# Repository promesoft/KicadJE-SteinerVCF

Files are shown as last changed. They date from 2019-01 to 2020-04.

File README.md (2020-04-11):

# Johansen Engineering Steiner VCF RevB

# Status - VCF working
## Initial 
| Stage  | Detail | Status |
| --- | --- | --- |
| create material  | sch/pcb | OK  |
| | gerber | OK |
| production  | | OK |
|  | produced | OK |
|  | delivered | Delivered |
## Preliminary validation
| Test  | Detail | Status |
| --- | --- | --- |
| Initial Inspection | VCO | OK - bottom looks empty w/o gnd fill |
| Initial Inspection | VCF | OK - bottom looks empty w/o gnd fill |
| | | Very difficult to mount as footprints are getting over soldering points in many places|
| | | BP in the bottom |
| | | HP in the middle |
| | | LP on top |
| Initial Inspection | VCF SMD | OK - bottom looks empty w/o gnd fill |
| Initial Technical Test | VCO | SINE has PCB error - and Sine pot has +12V to chassis |
| Initial Technical Test | VCF | One pot gets -12v on chassis |
| Initial Technical Test | VCF SMD |  |
| Initial Product Test | VCO | Nice -  |
| Initial Product Test | VCF |  |
| | | CV1 and CV2 works fine |
| | | Q is doing something |
| | | Uncertain if the freq pot is right |
| Initial Product Test | VCF SMD|  |
## Secondary validation
| Test  | Detail | Status |
| --- | --- |--- |
| Product Test |  | |
| Product Test |  |  |
| Quality | | |
| Quality | | |
| Long Term Product Test |  |  |
| Power Draw | VCO | +12 4mA -12
| Power Draw | VCF | +12 8mA -12
| Power Draw | VCF SMD | +12 ?mA -12

## Errata
### Errata - VCO
* Due to footprint one of the pots gets -12v on chassis

* Sine signal is shorted to GND

* Glide pot is reversed

### Errata - VCF
* Due to footprint one of the pots gets -12v on chassis

* R127 - DNP (Do not populate)

* R119 swap with 220nF-1uF to ac couple input stage

* R126 swap with 1uF to ac couple input stage

### Errata - VCF SMD

## Issues and Notes
### VCF
Very difficult to mount as footprints are getting over soldering points in many places
### VCO
 * Remove output pots
 * Collect jacks in the bottom
 * Fix errors (glide,  POT, PCB errors, footprint tightened)
 * Consider removing sine shaper
# Pictures
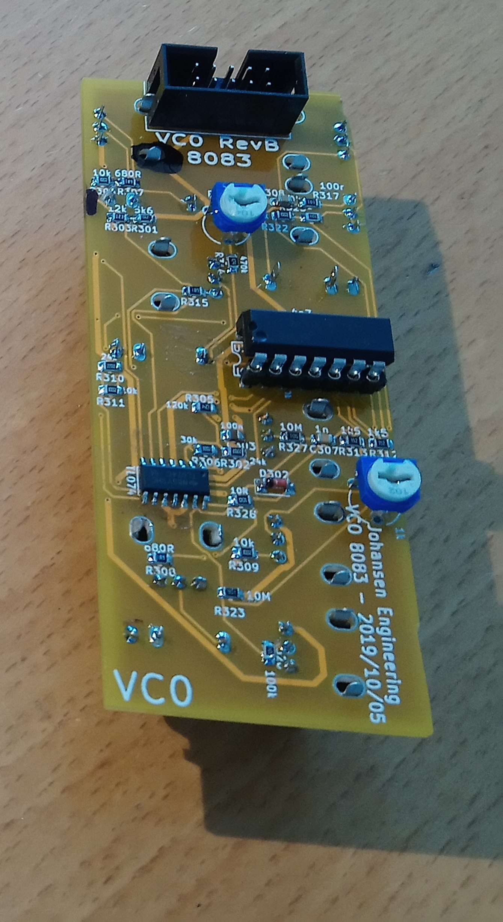
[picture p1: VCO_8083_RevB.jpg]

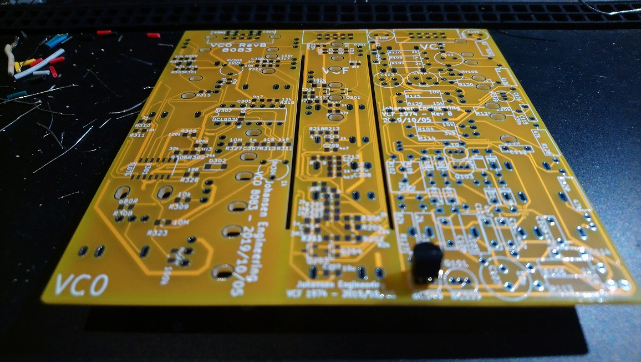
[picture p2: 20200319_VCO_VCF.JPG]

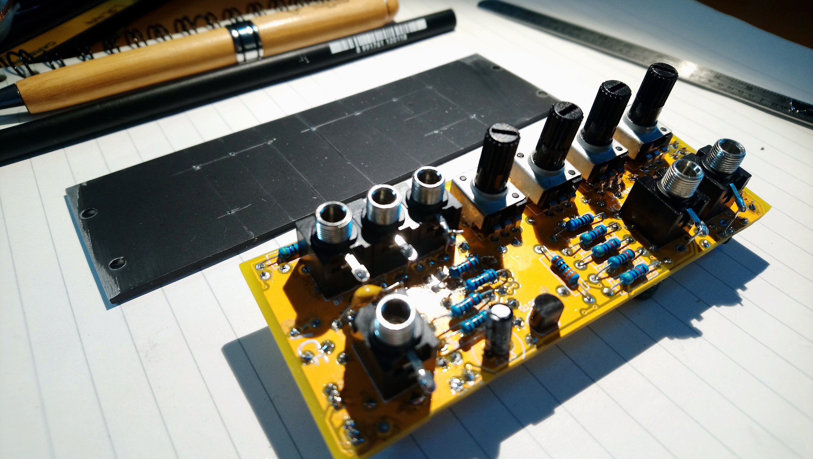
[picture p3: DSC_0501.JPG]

# Schematic
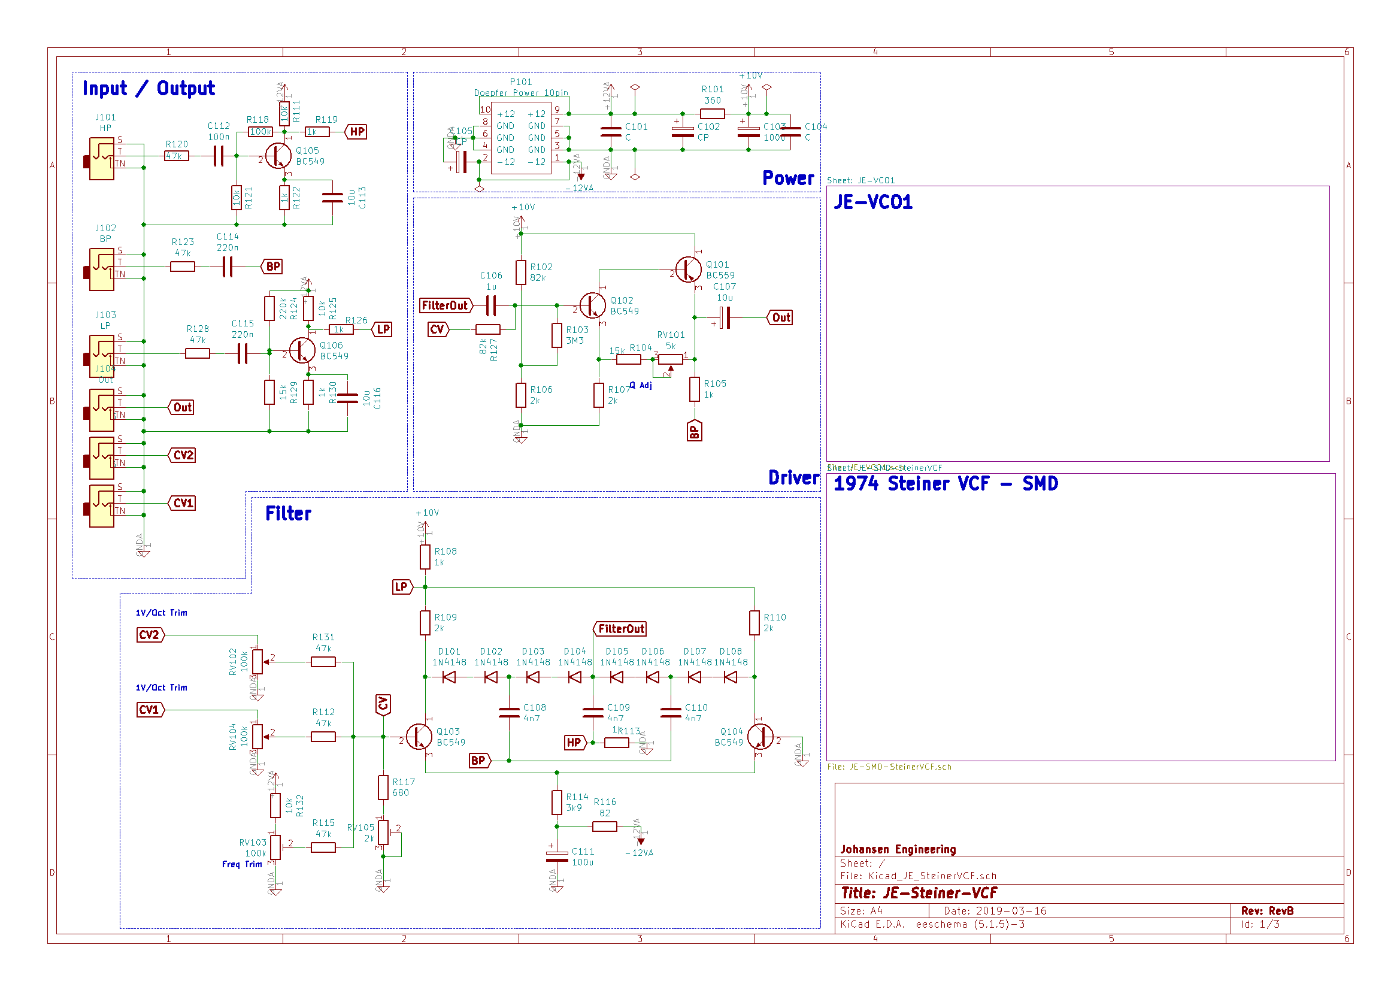
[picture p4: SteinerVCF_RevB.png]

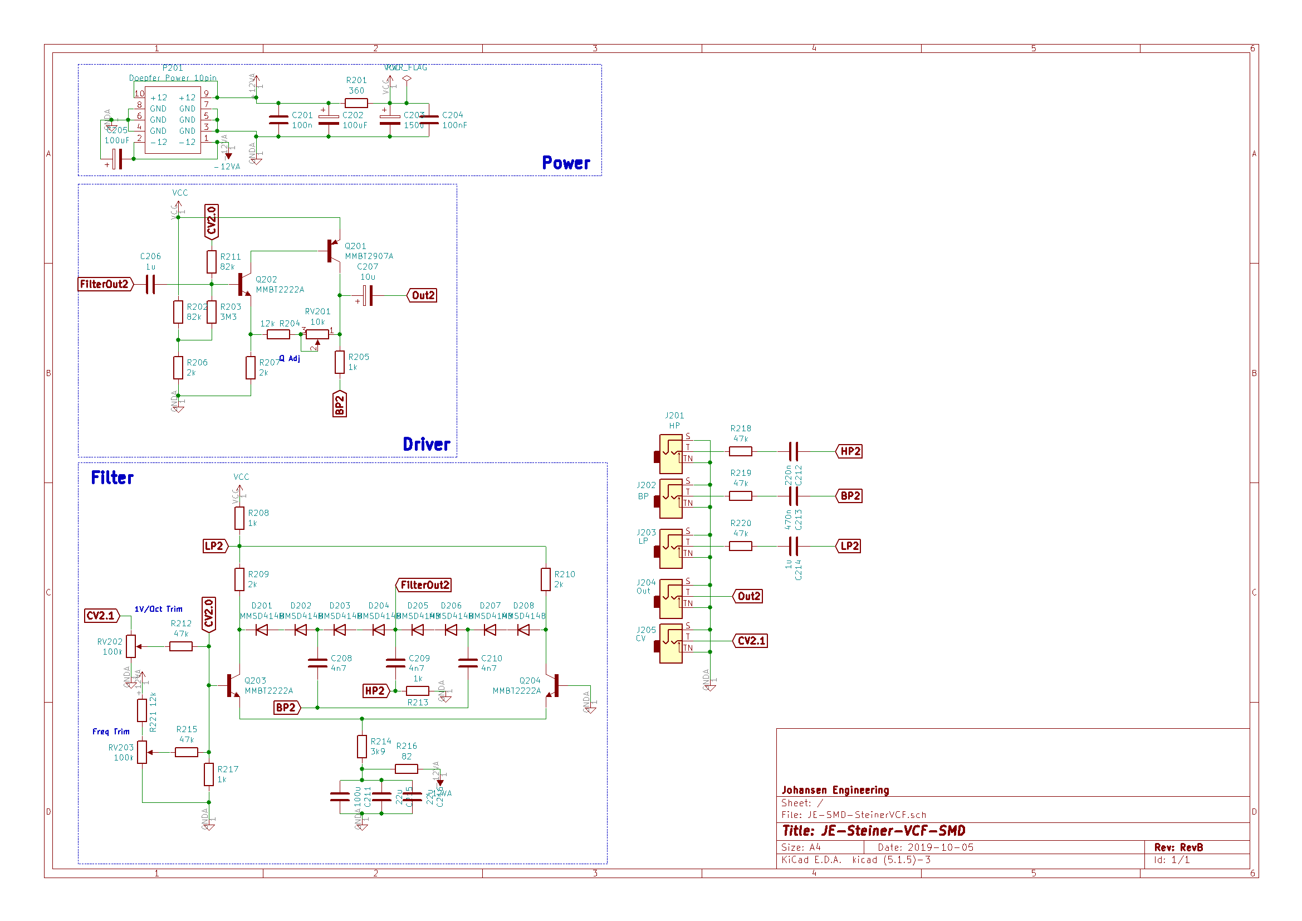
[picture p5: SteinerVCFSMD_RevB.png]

# Layout

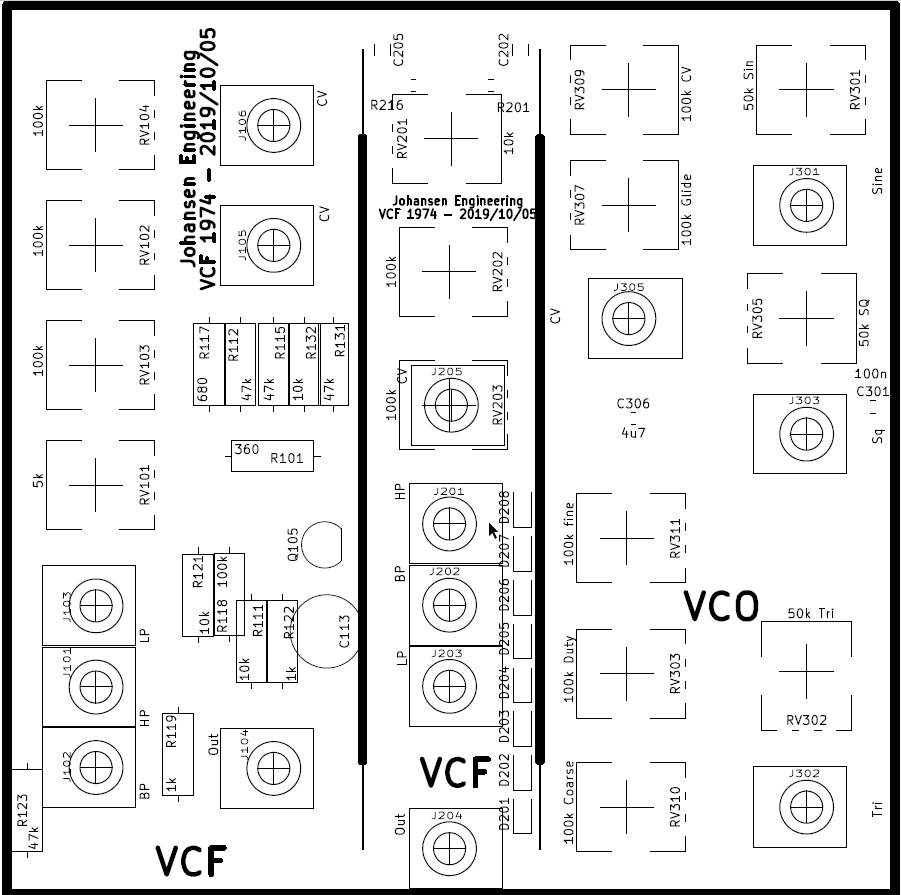
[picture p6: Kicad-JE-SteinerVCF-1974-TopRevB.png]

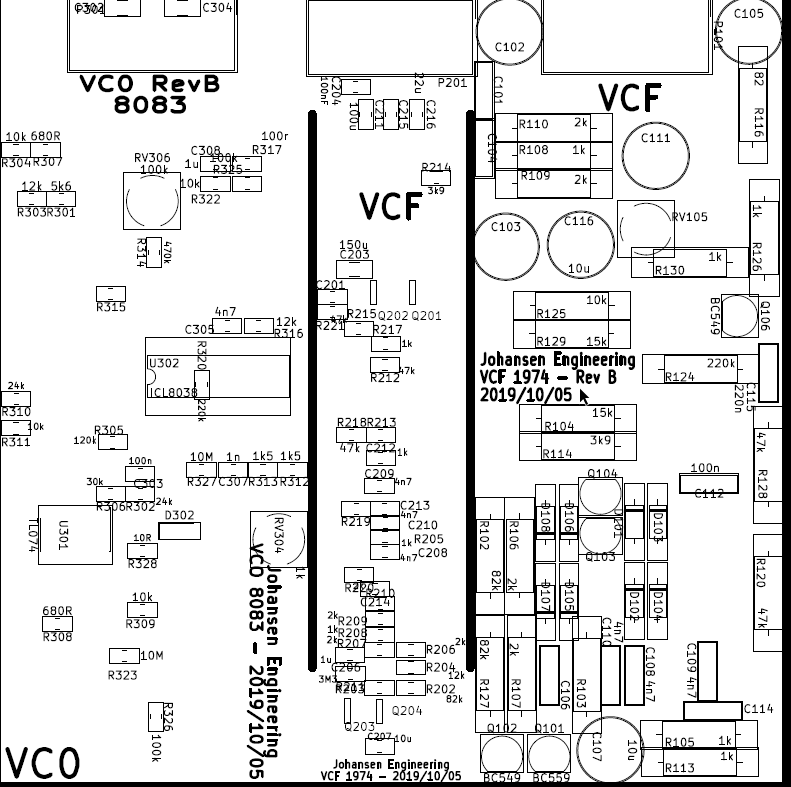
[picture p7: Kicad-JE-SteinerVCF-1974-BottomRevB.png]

# Inspiration

-----------------------

# Johansen Engineering Steiner VCF

# Purpose
Test some of the original designs for inspiration and reference.

# Status - Preliminary tests
## Initial 
| Stage  | Detail | Status |
| --- | --- | --- |
| create material  | sch/pcb | produced Rev A  |
| | gerber | produced and uploaded RevA |
| production  | ordered  | OK |
|  | produced | OK |
|  | delivered | OK |
## Preliminary validation
| Test  | Detail | Status |
| --- | --- | --- |
| Initial Inspection | THT VCF - Visual - Component Mounting | NOT OK |
| Initial Inspection | SMD VCF - Visual - Component Mounting | NOT OK |
| Initial Inspection | VCO  - Visual - Component Mounting | OK |
| Initial Technical Test | THT VCF - Base operation | NOT OK |
| | Knobs | Freq working for LP - Q for HP/BP - CV trim - not ok|
| Initial Technical Test | SMD VCF | NOT TESTED |
| Initial Technical Test | VCO  - Sine - Triangle - Square | OK |
| | Trimmers | OK |
| | Knobs | OK |
| Initial Product Test | VCO CV from LFO | OK |
| | VCO Vactrol CV from LFO | no real effect with CV coupling |

## Secondary validation
| Test  | Detail | Status |
| --- | --- |--- |
| Product Test | VCF | |
| Product Test | VCO | Works nicely - frequency is a bit high |
| Quality | VCF | |
| Quality | VCO | |
| Long Term Product Test | VCO | OpAmp gets hot - esp if no output is conn to the square |
| Power Draw | VCO | 50-120mA depending on output...

## Errata
### Errata - THT VCF
 * C111 reverse polarity
 * R102 should go from +10v to connection between R103 and R106 - and +10v sould not go to Q102 base - Critical
### Errata - SMD VCF
 * R should go from +10v to connection between R and R - and +10v sould not go to Q base - Critical
### Errata - VCO
 * 470K values not correct for all resistors
 * 0R values not correct - fixed in RevB
 * Outputs should not be shorted to GND when not connected
 
## Issues and Notes
### VCF THT/SMD
 * The filter needs adjustments and the feedback is not stable. a 56k from CV to base of Q102 helps a bit.
 * Input circuit for CV needs rework
 * Input series resistor and capacitor could be a good addon for the filter inputs
 * Frequency adjust seems to work for LP only
 * Q adjust is minor and seems to work on HP and a bit on BP

### VCO
 * Tweak values for better frequency range
 * Op Amp can get hot
 * Draws more power if nothing is inserted into the Square output?

# Physical Construction
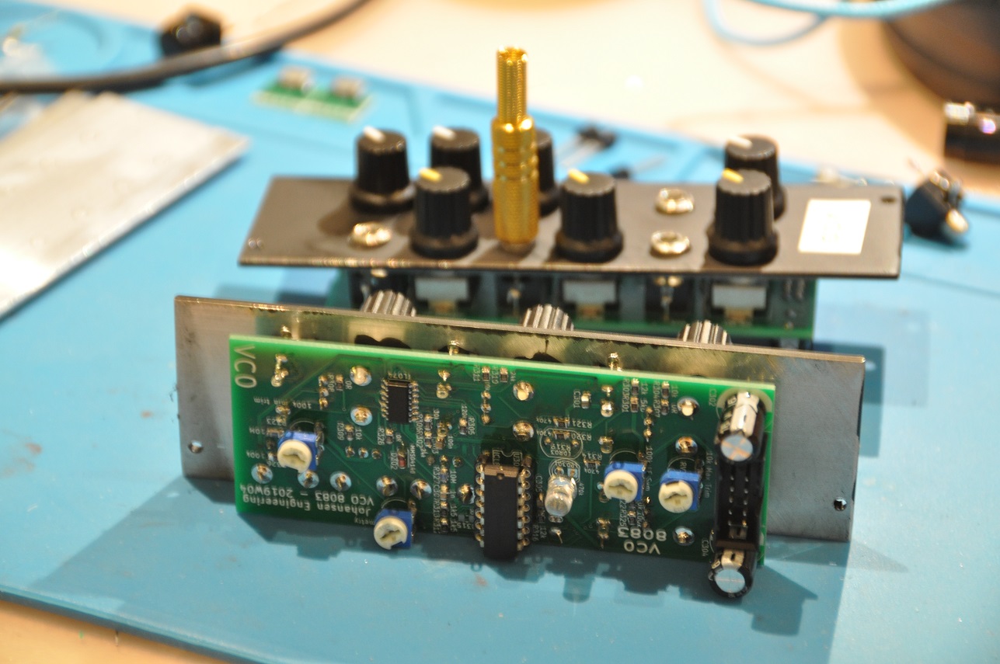
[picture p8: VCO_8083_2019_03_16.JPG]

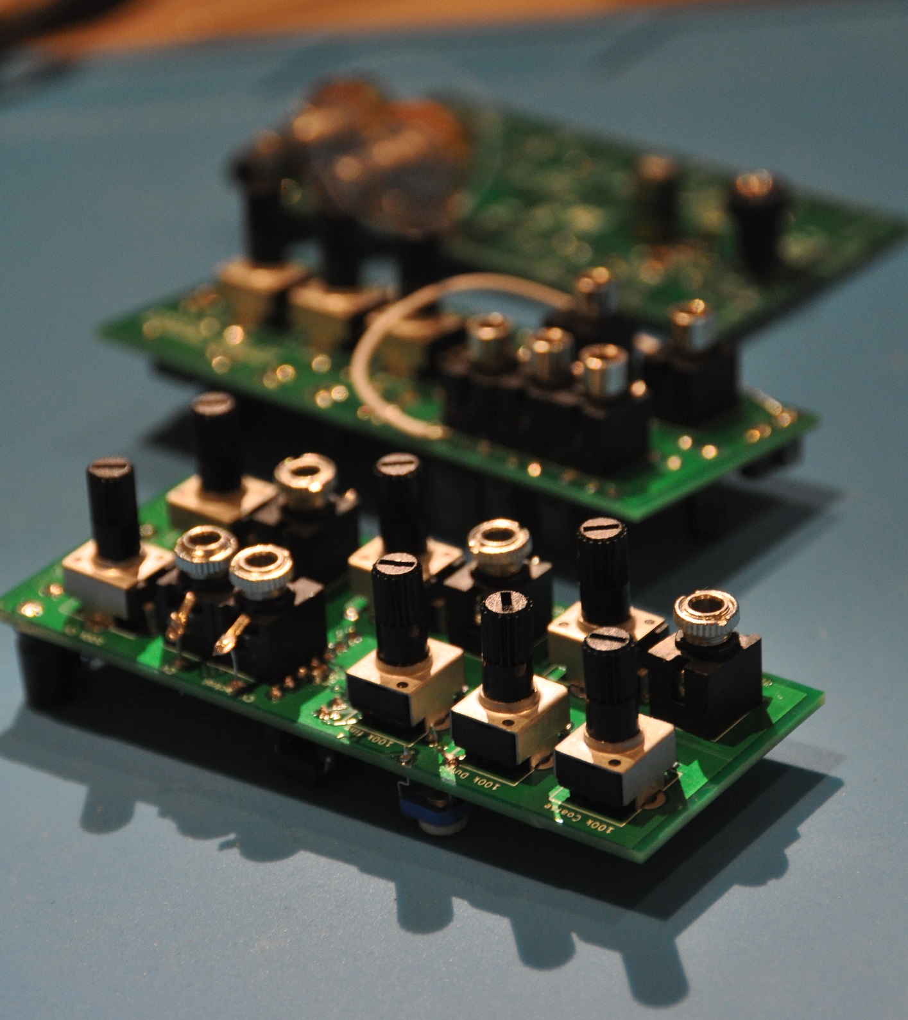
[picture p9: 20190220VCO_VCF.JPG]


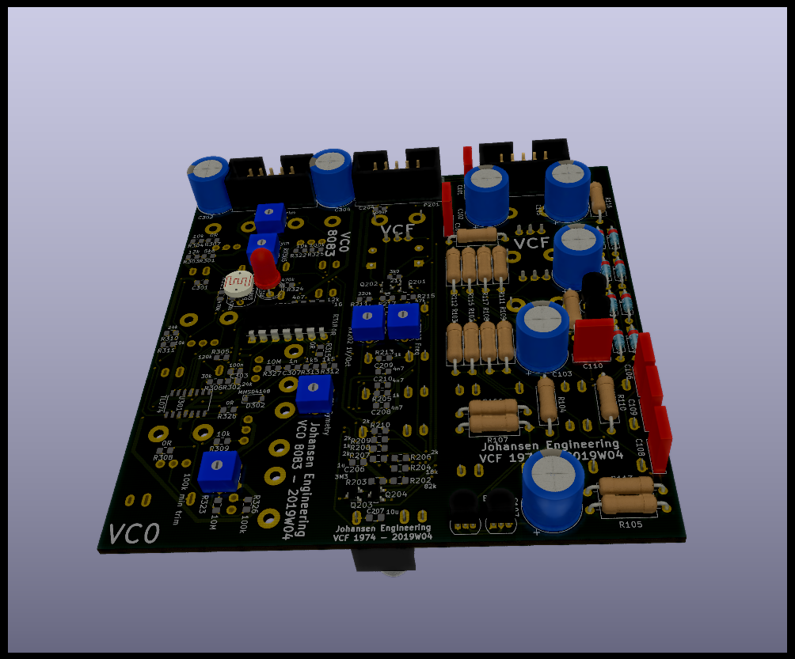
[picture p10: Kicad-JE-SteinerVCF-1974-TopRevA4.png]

# Features

## SMD VCF Schematic
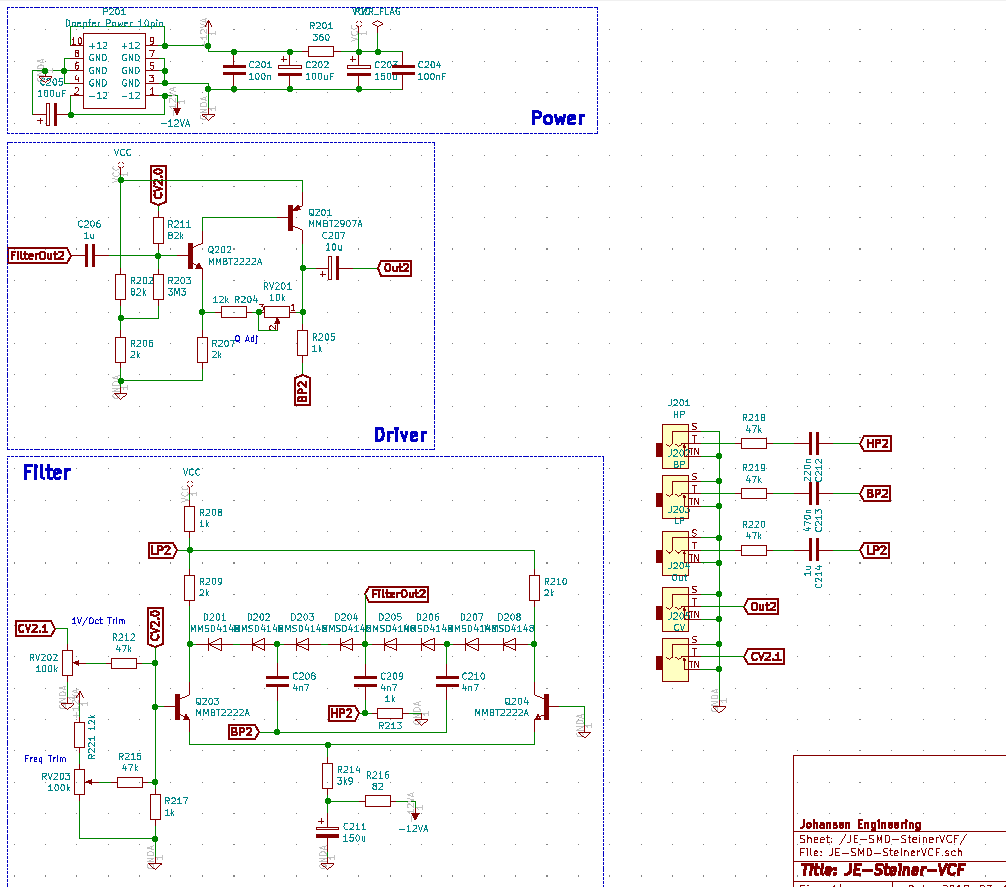
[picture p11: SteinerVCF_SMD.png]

## VCO Schematic
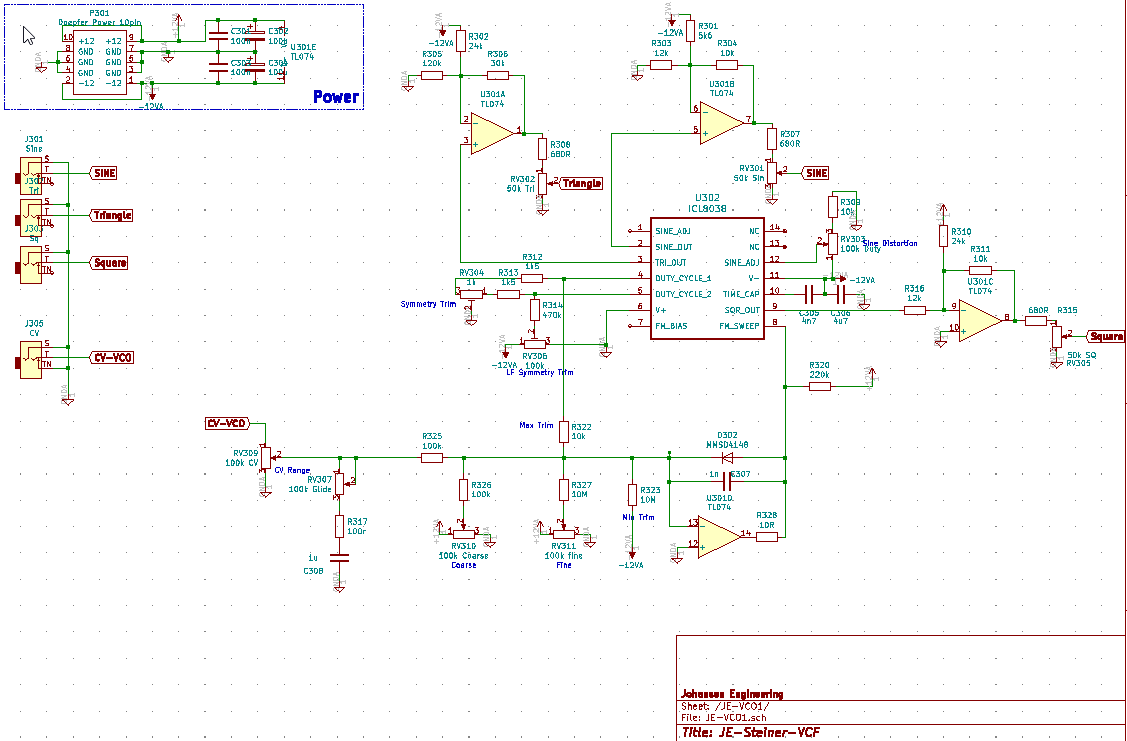
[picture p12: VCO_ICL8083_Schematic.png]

# Inspirational sources:
## Steiner VCF 1974 THT
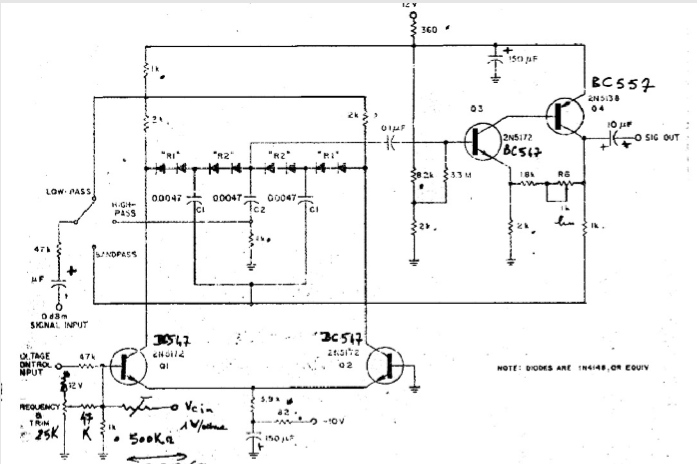
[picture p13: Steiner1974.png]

## Steiner VCF 1974 SMD
Same schematic - different components - half the size

## VCO ICL 8083
Based on a Thomas Henry schematic
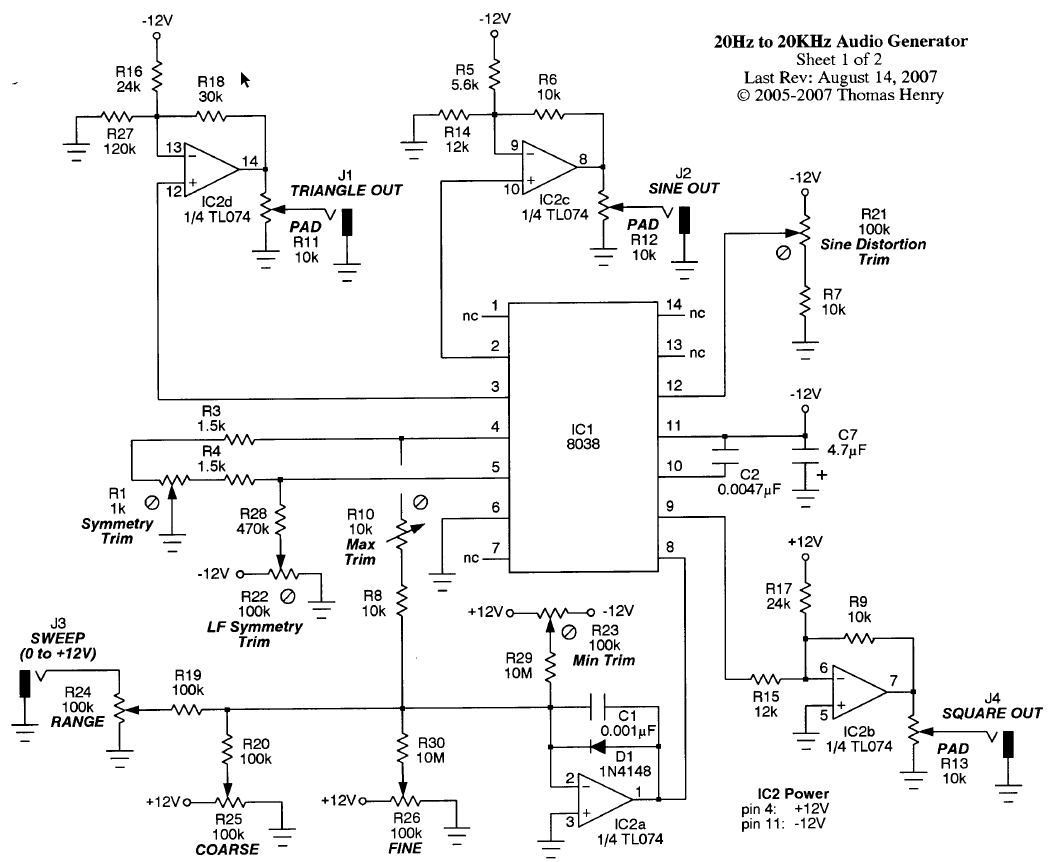
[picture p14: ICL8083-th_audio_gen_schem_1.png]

# Details

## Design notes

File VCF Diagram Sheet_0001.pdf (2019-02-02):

## ilns

## IHa TI A*

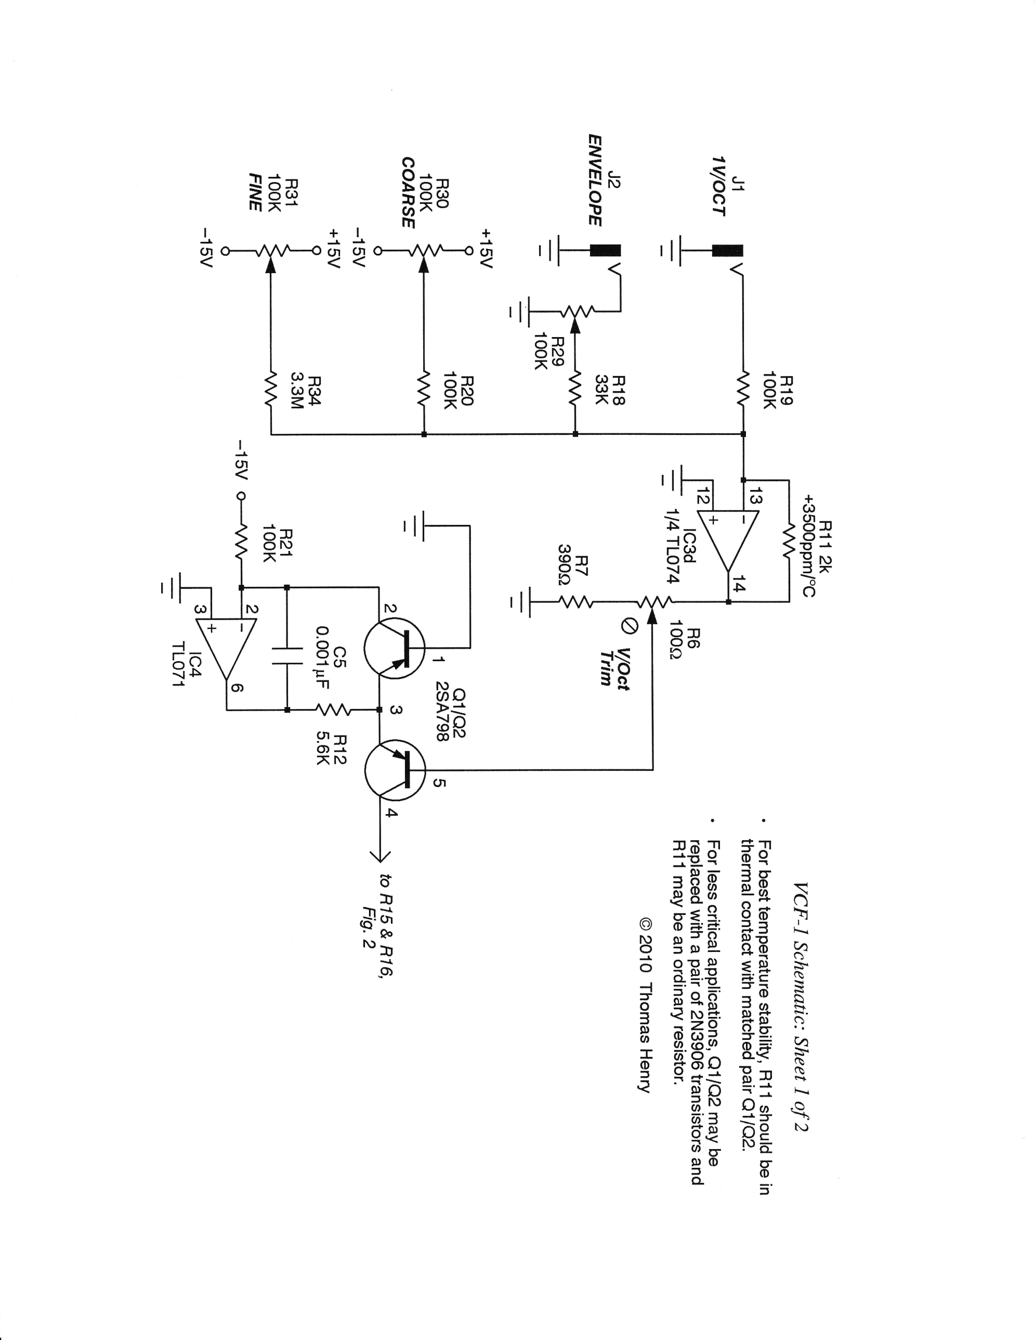
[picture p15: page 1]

S=o
a

rn

### =ffi- F f\)

o
!
rn

o
Q-r.-
n
+
..^(lt

+l
JJ(Jr (Fl

I
J,
(Jt

dru
5<o
ETxo

I
J
(lt
rl
+
(r)8r o-r. E-r E r\) 3x

o

o

J

s_
-rOrG) bo- N
s

(^)
H{

ofI
Eo.,

s

SEsg

{
5R | Bo>{

HC

# is{ tq

## Eilq *g E

## ,a ]c8. Ub' t

(J, o='=. +3 i.-.

# E silE HE K d:.EfiiPY

### # il-ail' lH $

3

# ft$HiilFF g ggg ga s

## d ru gE 'e.. 6'3 qE Ri N)

@ o l-o' 3.' q

s
b
.$* *r

-9)

p
8o
-r. (J1
.TI

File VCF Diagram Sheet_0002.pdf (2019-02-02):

# =b(n. pEh

b

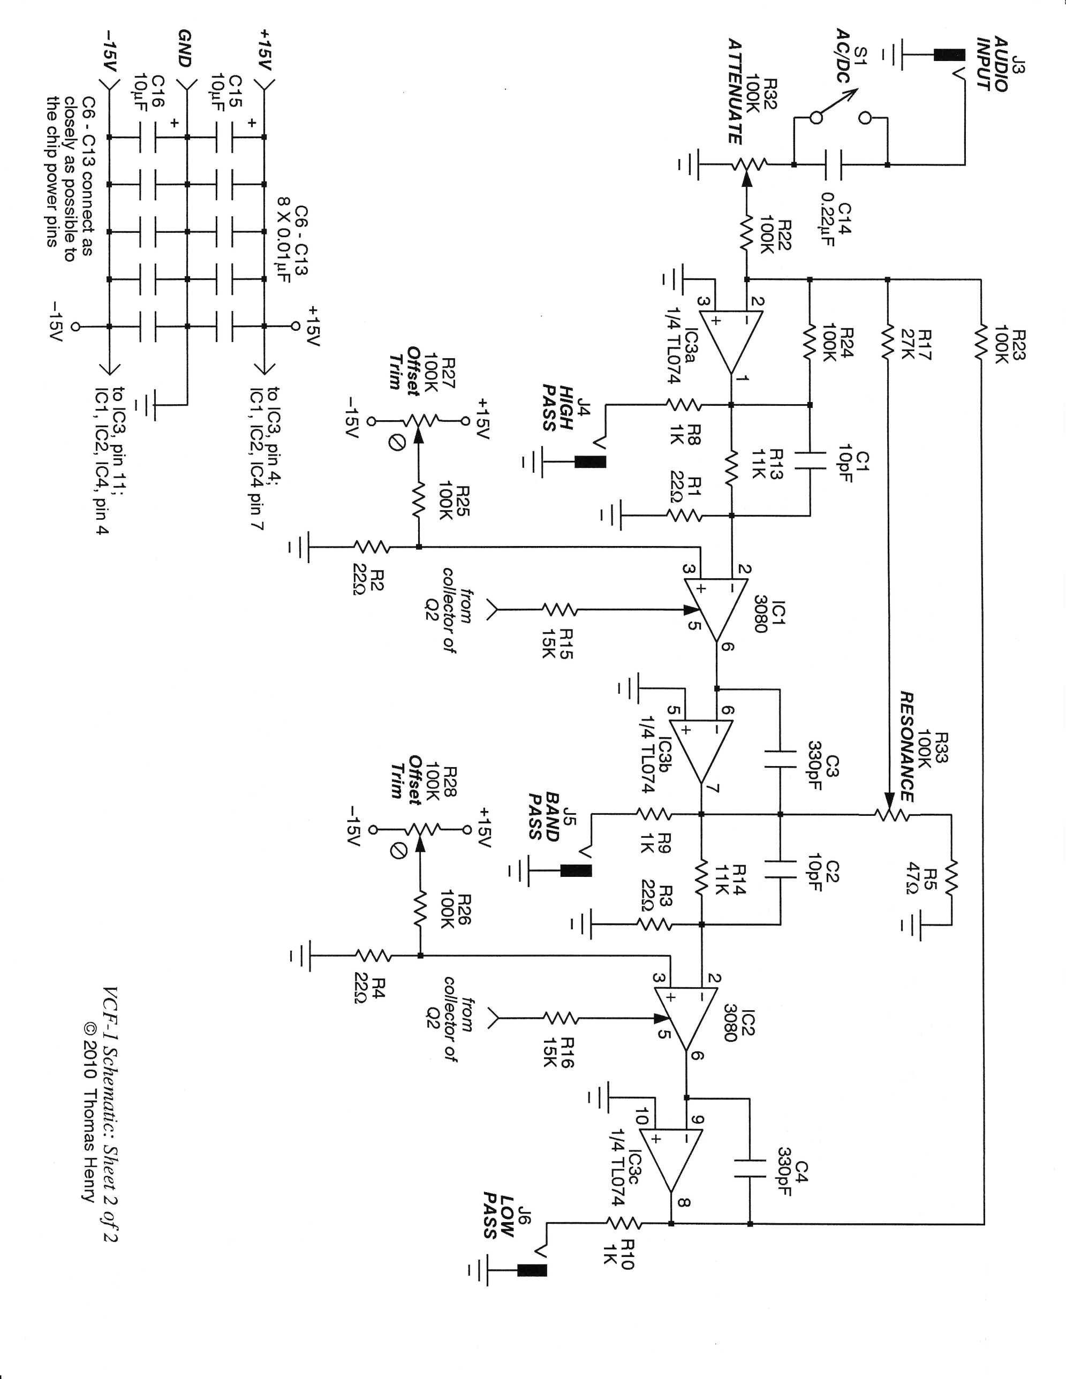
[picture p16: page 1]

\- qr io

# Qoq) "r o

o

# luO

# nru

Pi

@
x$

# 9l qo

\c,r

# dru 5 <r)

.J,

s_

# -rOr- G) bs) \ls

rl

## bahl

# Hnru t

+oo
l-43
E;q

# : o.6 9.oo

a 6-;'
6o
rl

# -Ln Xco

J, -t
-Jt /\@

+

### ..4(lt I

(Jt

# $$dru s Ex!

# e Er- I J

(Jt

# ooo

6J' Np.

R+
p. J\

# ooo

oJ')
J\)E.

# O..^ S.-r

## p.fs

N- i$r | I
P tu | oFd' *qso\

rl

rl

Nn fA' J,

### rrJ

J, TI

## crr

a

# xcrt

6
G) u

## .Js{ro{

# $fins

s
TE

# + bbc- E EE' I

J,
(Ft
rl
Na

d47\o)

N'-'
O

# Ed5 q$$

";

d\
6 r'
v l-...

# Hr o$"

# -rSs's qR. JA

$ t'
@C4
+\rI r\)
d-R
aN)\

t\)

6
G) o

J,s{

r-o{
!r

# 5 birc-

E='

# ..r JI

--L/\o

+{

Ot

# oeU I{

(Jt

# nru

J,

# lo oO

r\)
T

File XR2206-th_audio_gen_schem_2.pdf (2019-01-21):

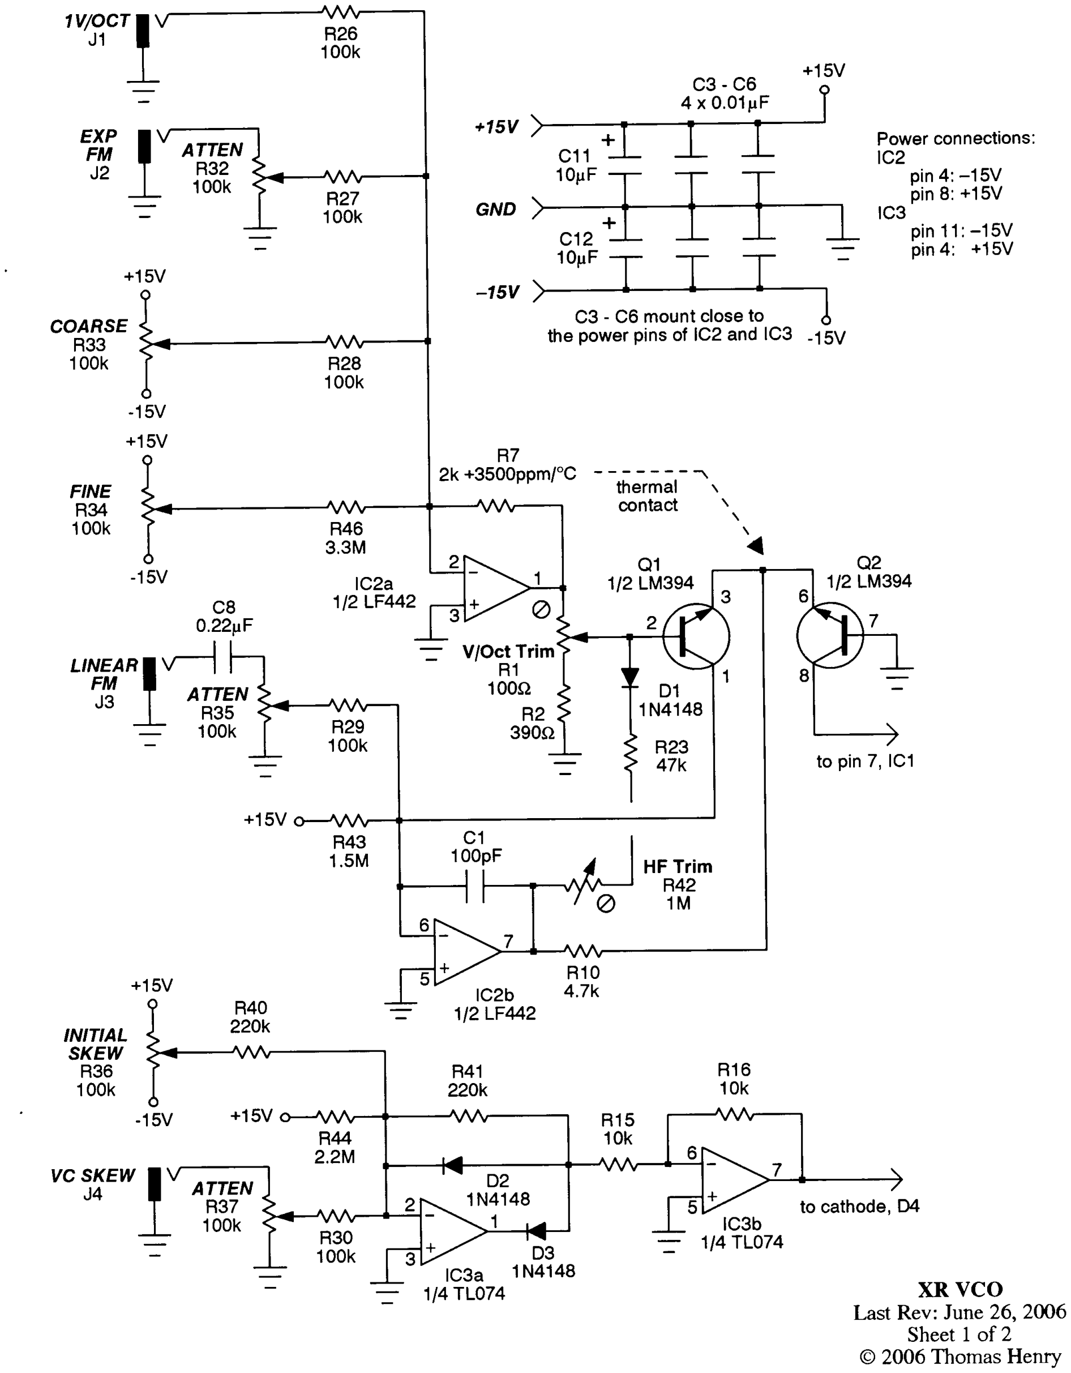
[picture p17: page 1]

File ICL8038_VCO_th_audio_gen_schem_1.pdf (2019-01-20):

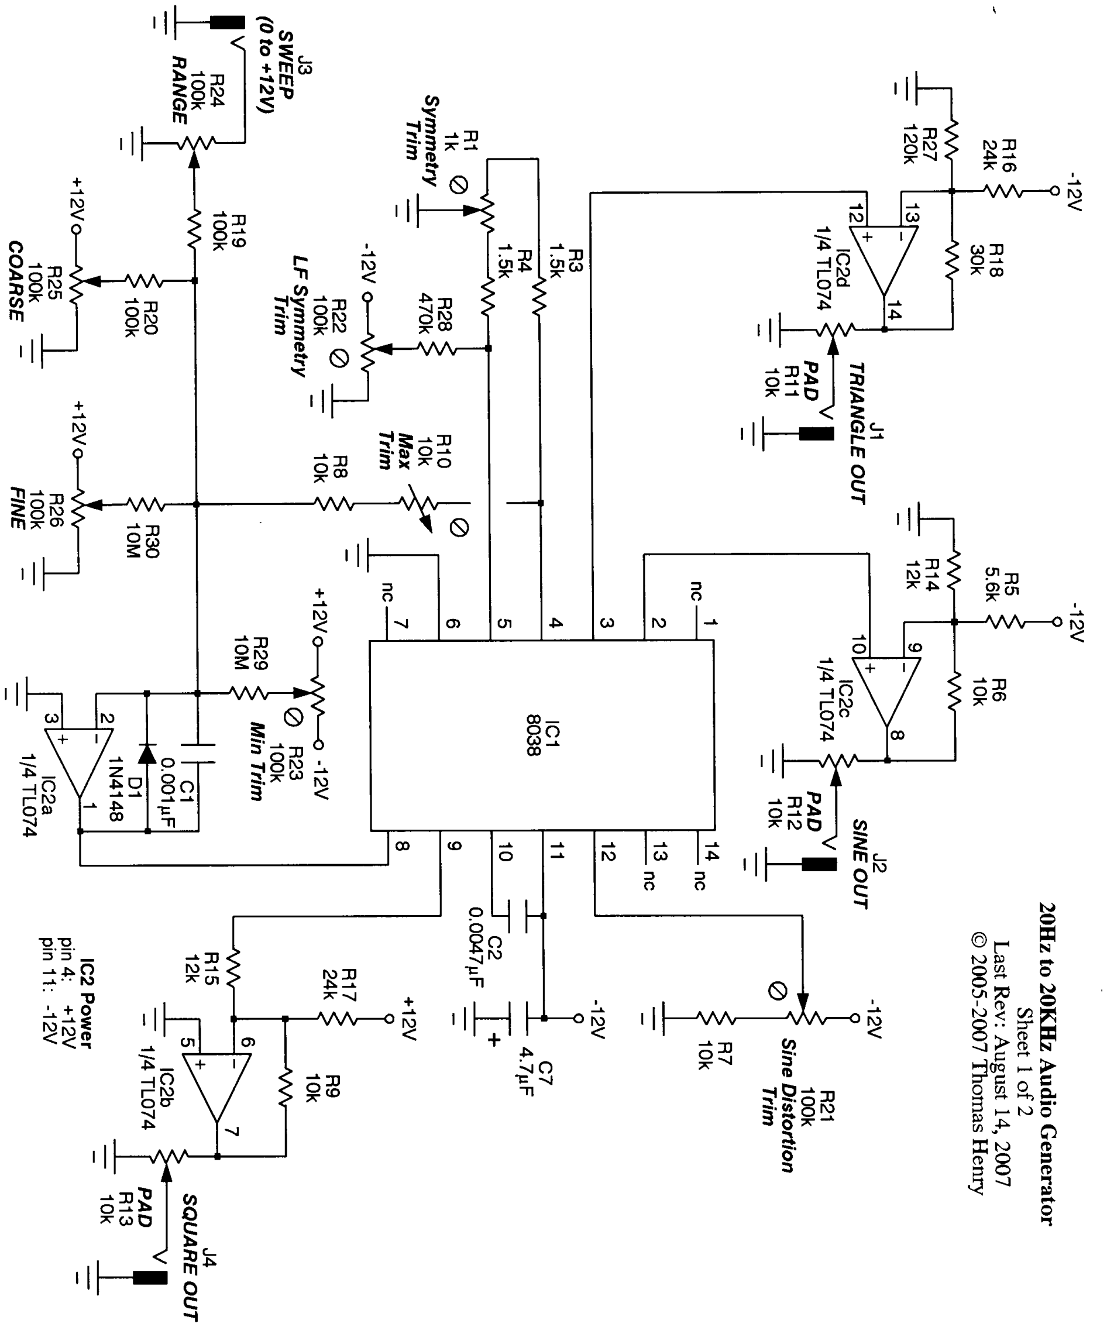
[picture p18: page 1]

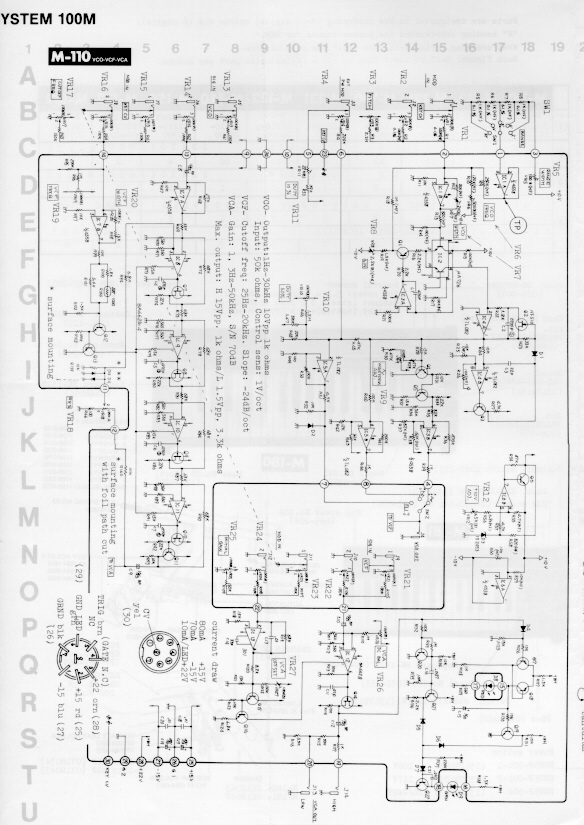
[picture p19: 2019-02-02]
VCO_schematic_s100m02b.jpg

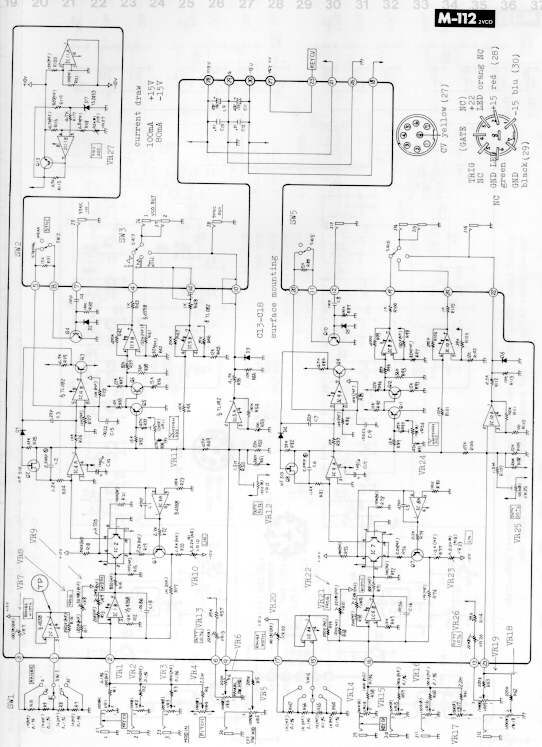
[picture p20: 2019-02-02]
VCO_schematic_s100m03b.jpg

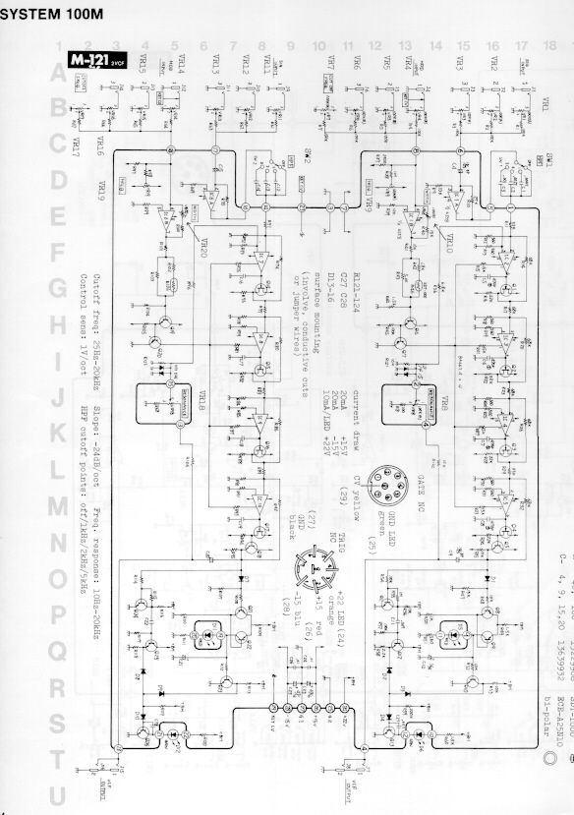
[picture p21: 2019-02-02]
VCF_schematic_s100m04b.jpg

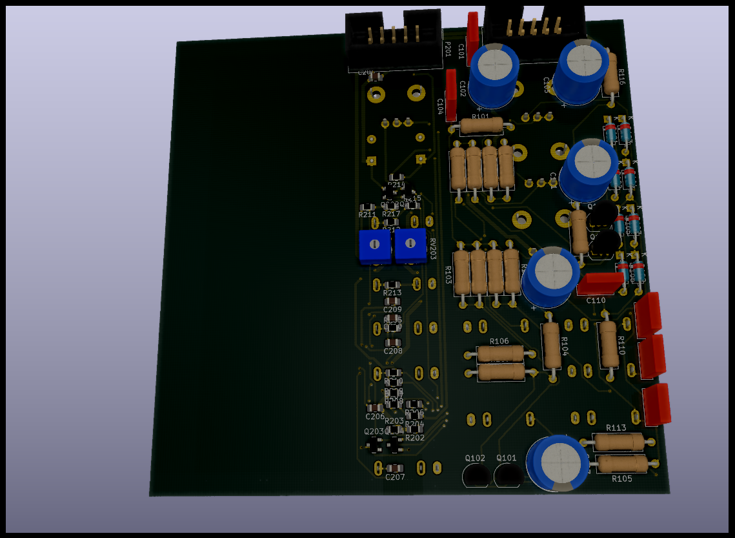
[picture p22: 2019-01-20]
Kicad-JE-SteinerVCF-1974-TopRevA1.png

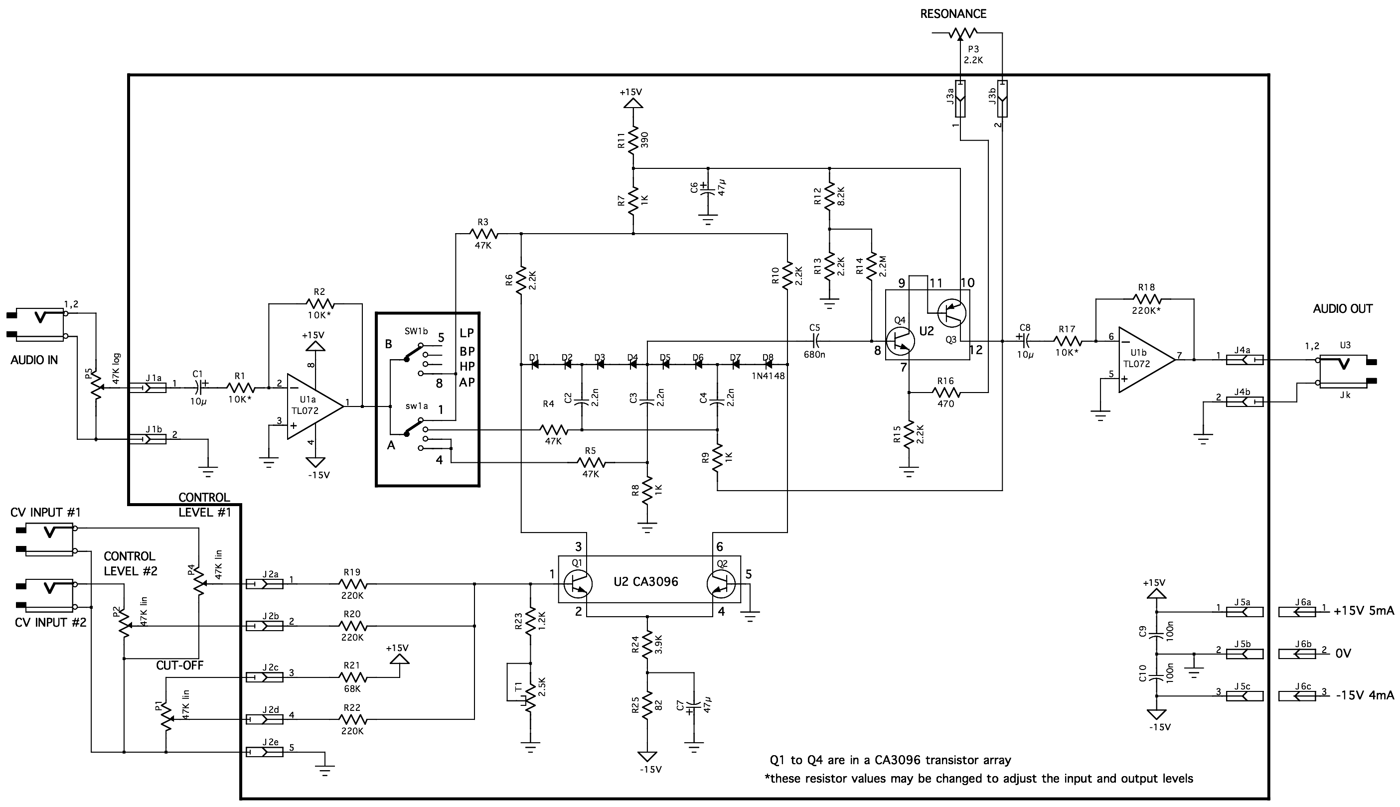
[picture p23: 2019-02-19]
VCF-CA3096-sch-yusynth.net.gif

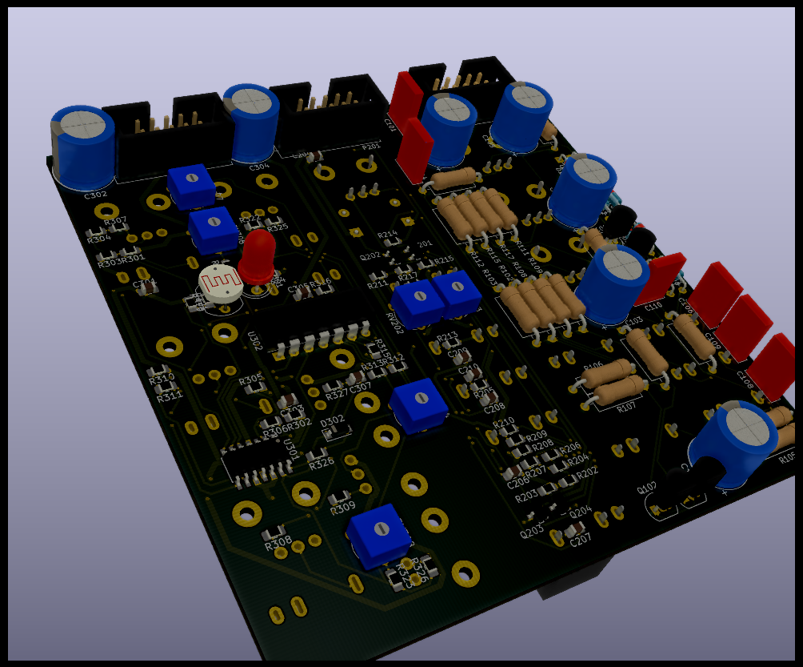
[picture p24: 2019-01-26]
Kicad-JE-SteinerVCF-1974-TopRevA3.png

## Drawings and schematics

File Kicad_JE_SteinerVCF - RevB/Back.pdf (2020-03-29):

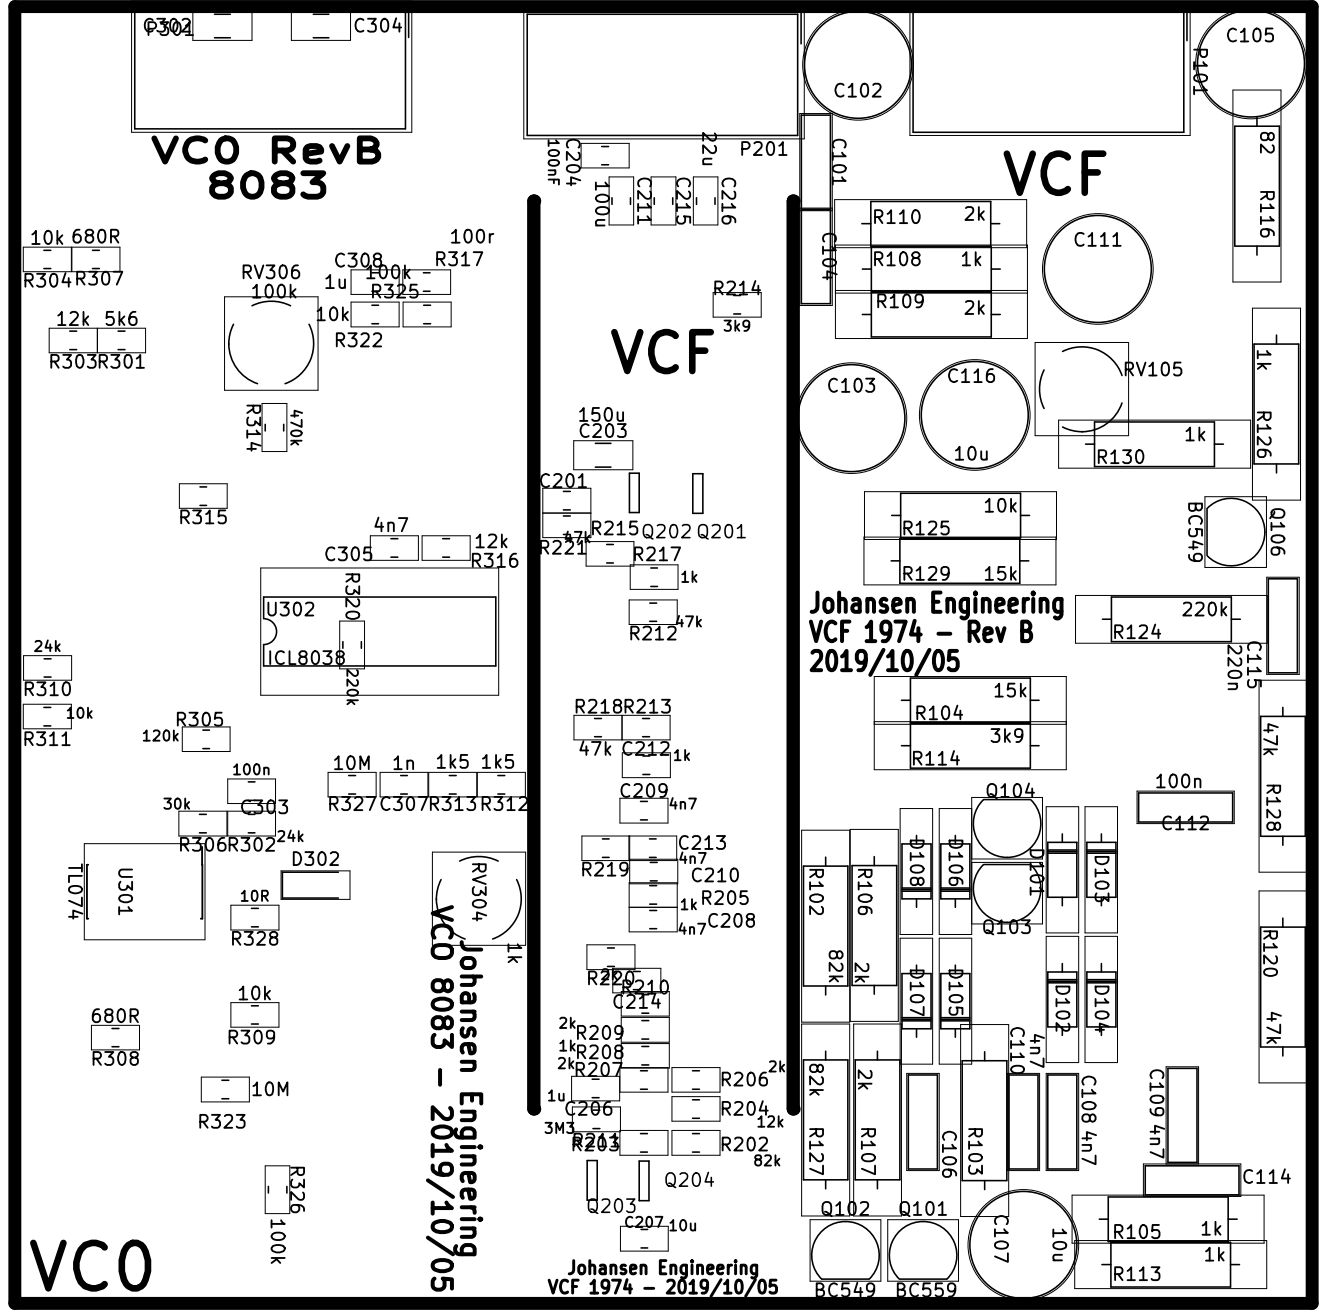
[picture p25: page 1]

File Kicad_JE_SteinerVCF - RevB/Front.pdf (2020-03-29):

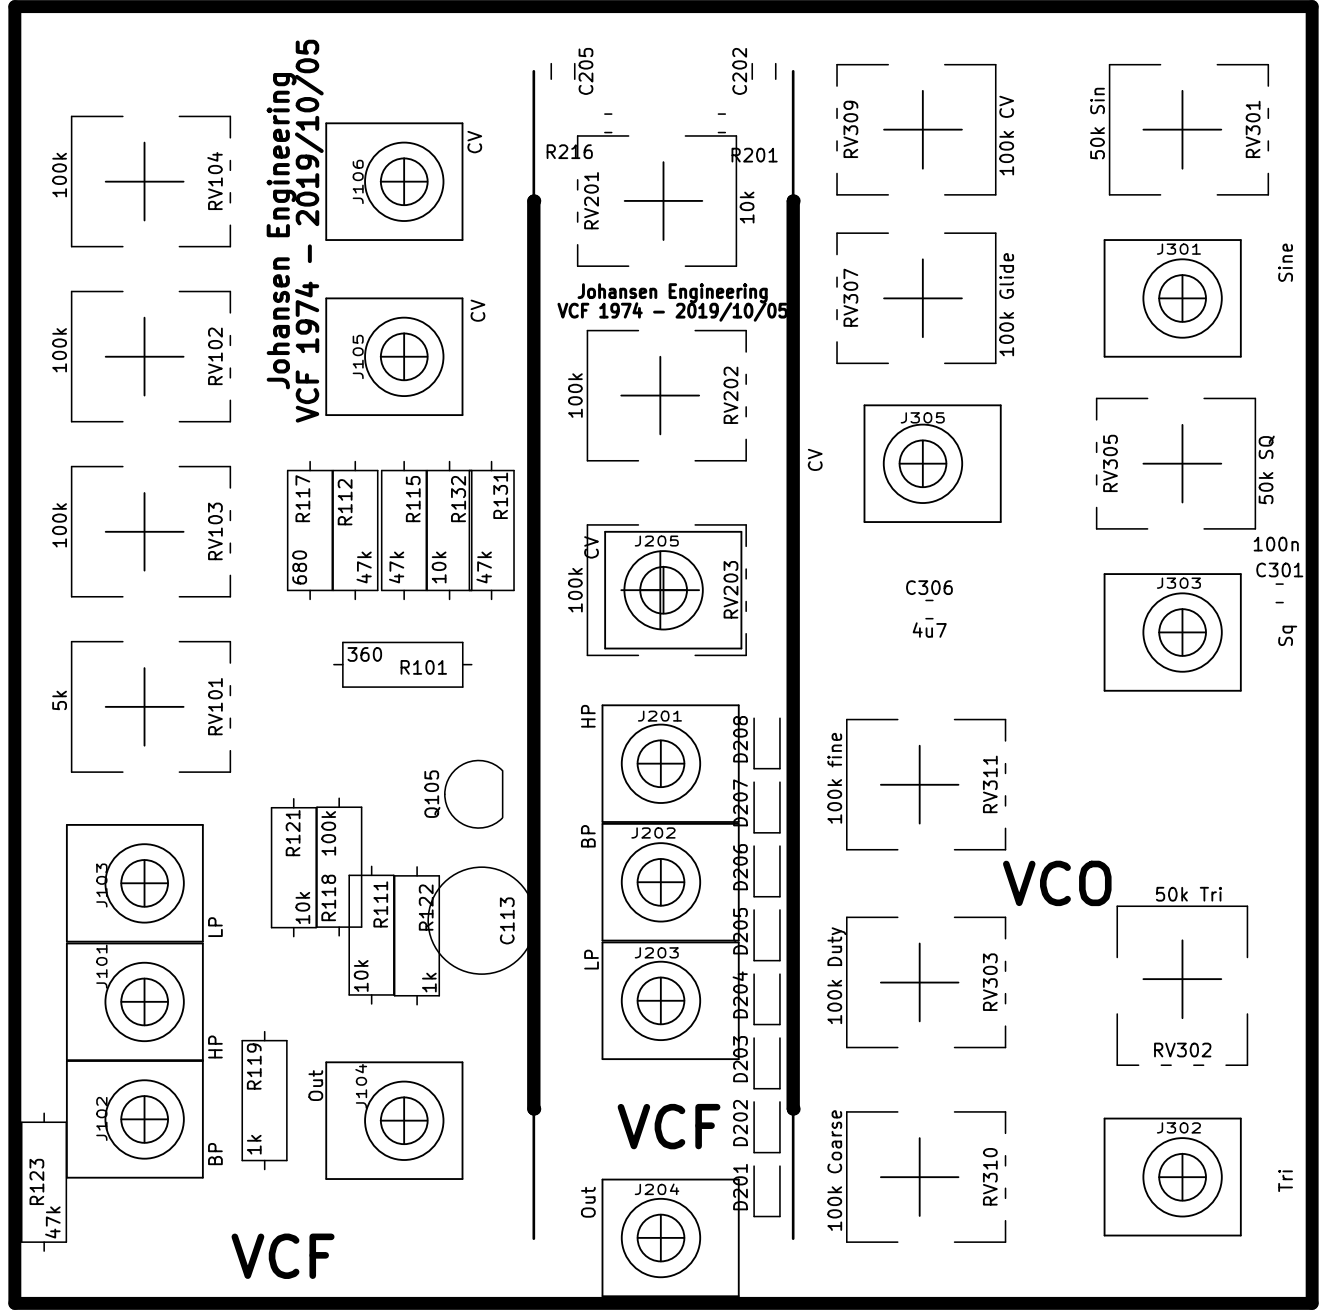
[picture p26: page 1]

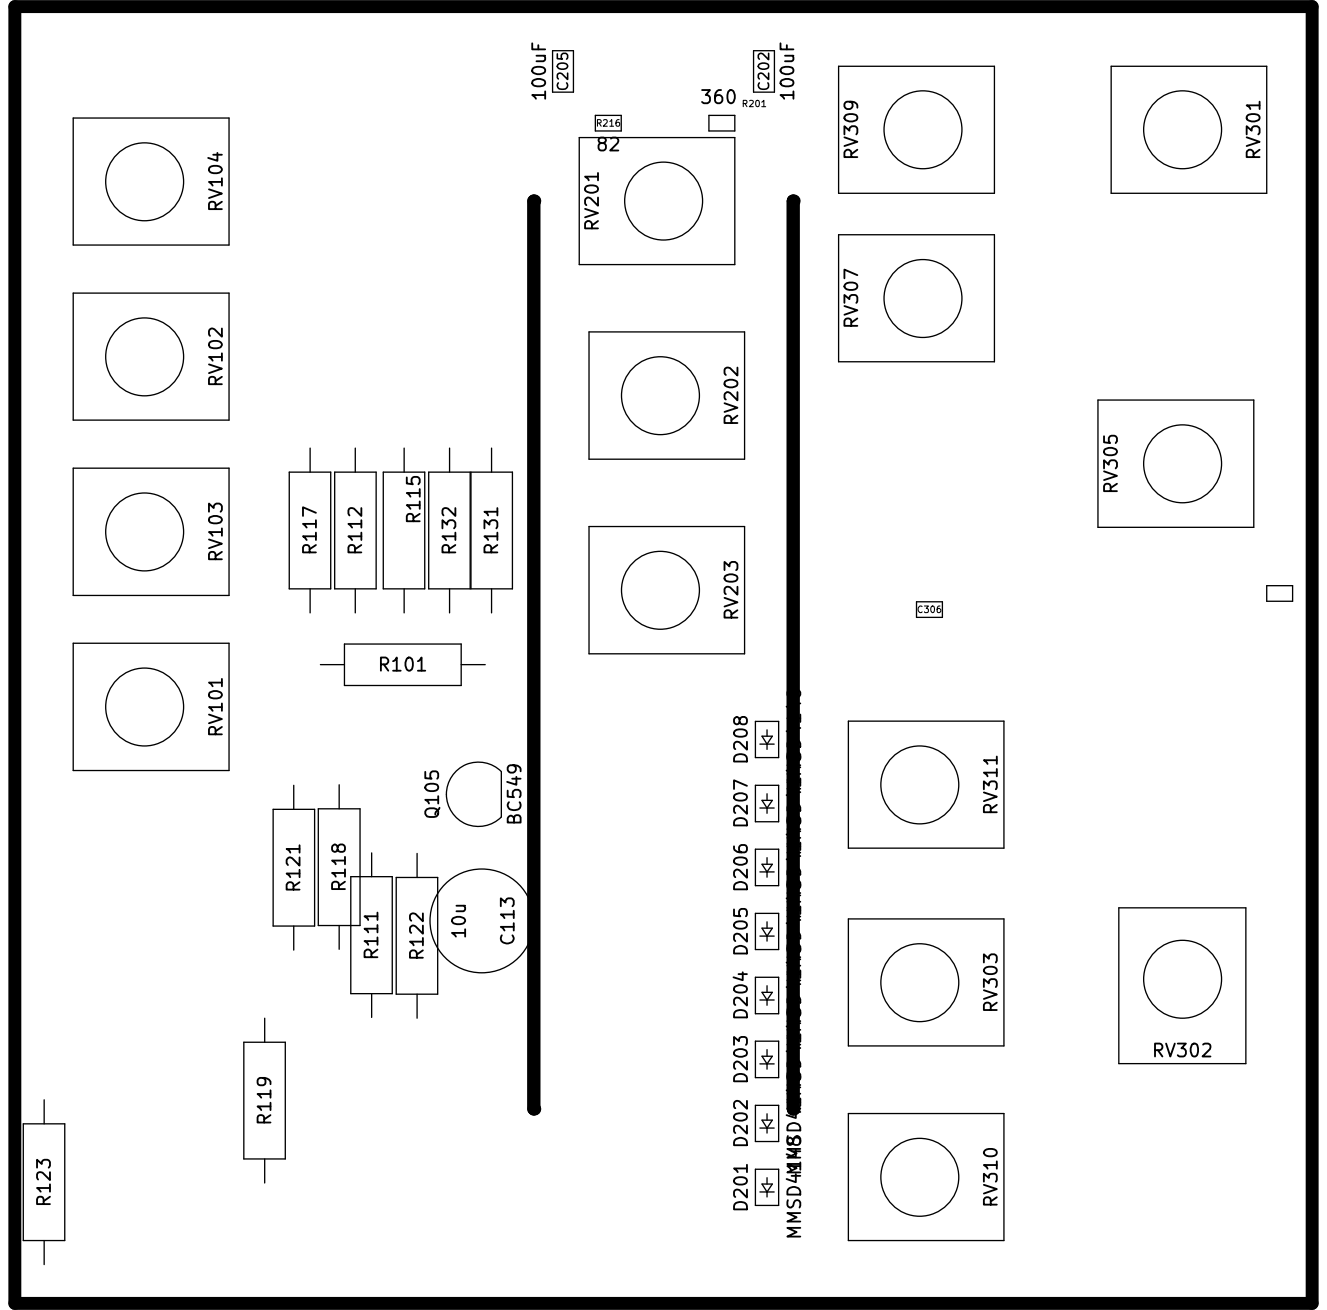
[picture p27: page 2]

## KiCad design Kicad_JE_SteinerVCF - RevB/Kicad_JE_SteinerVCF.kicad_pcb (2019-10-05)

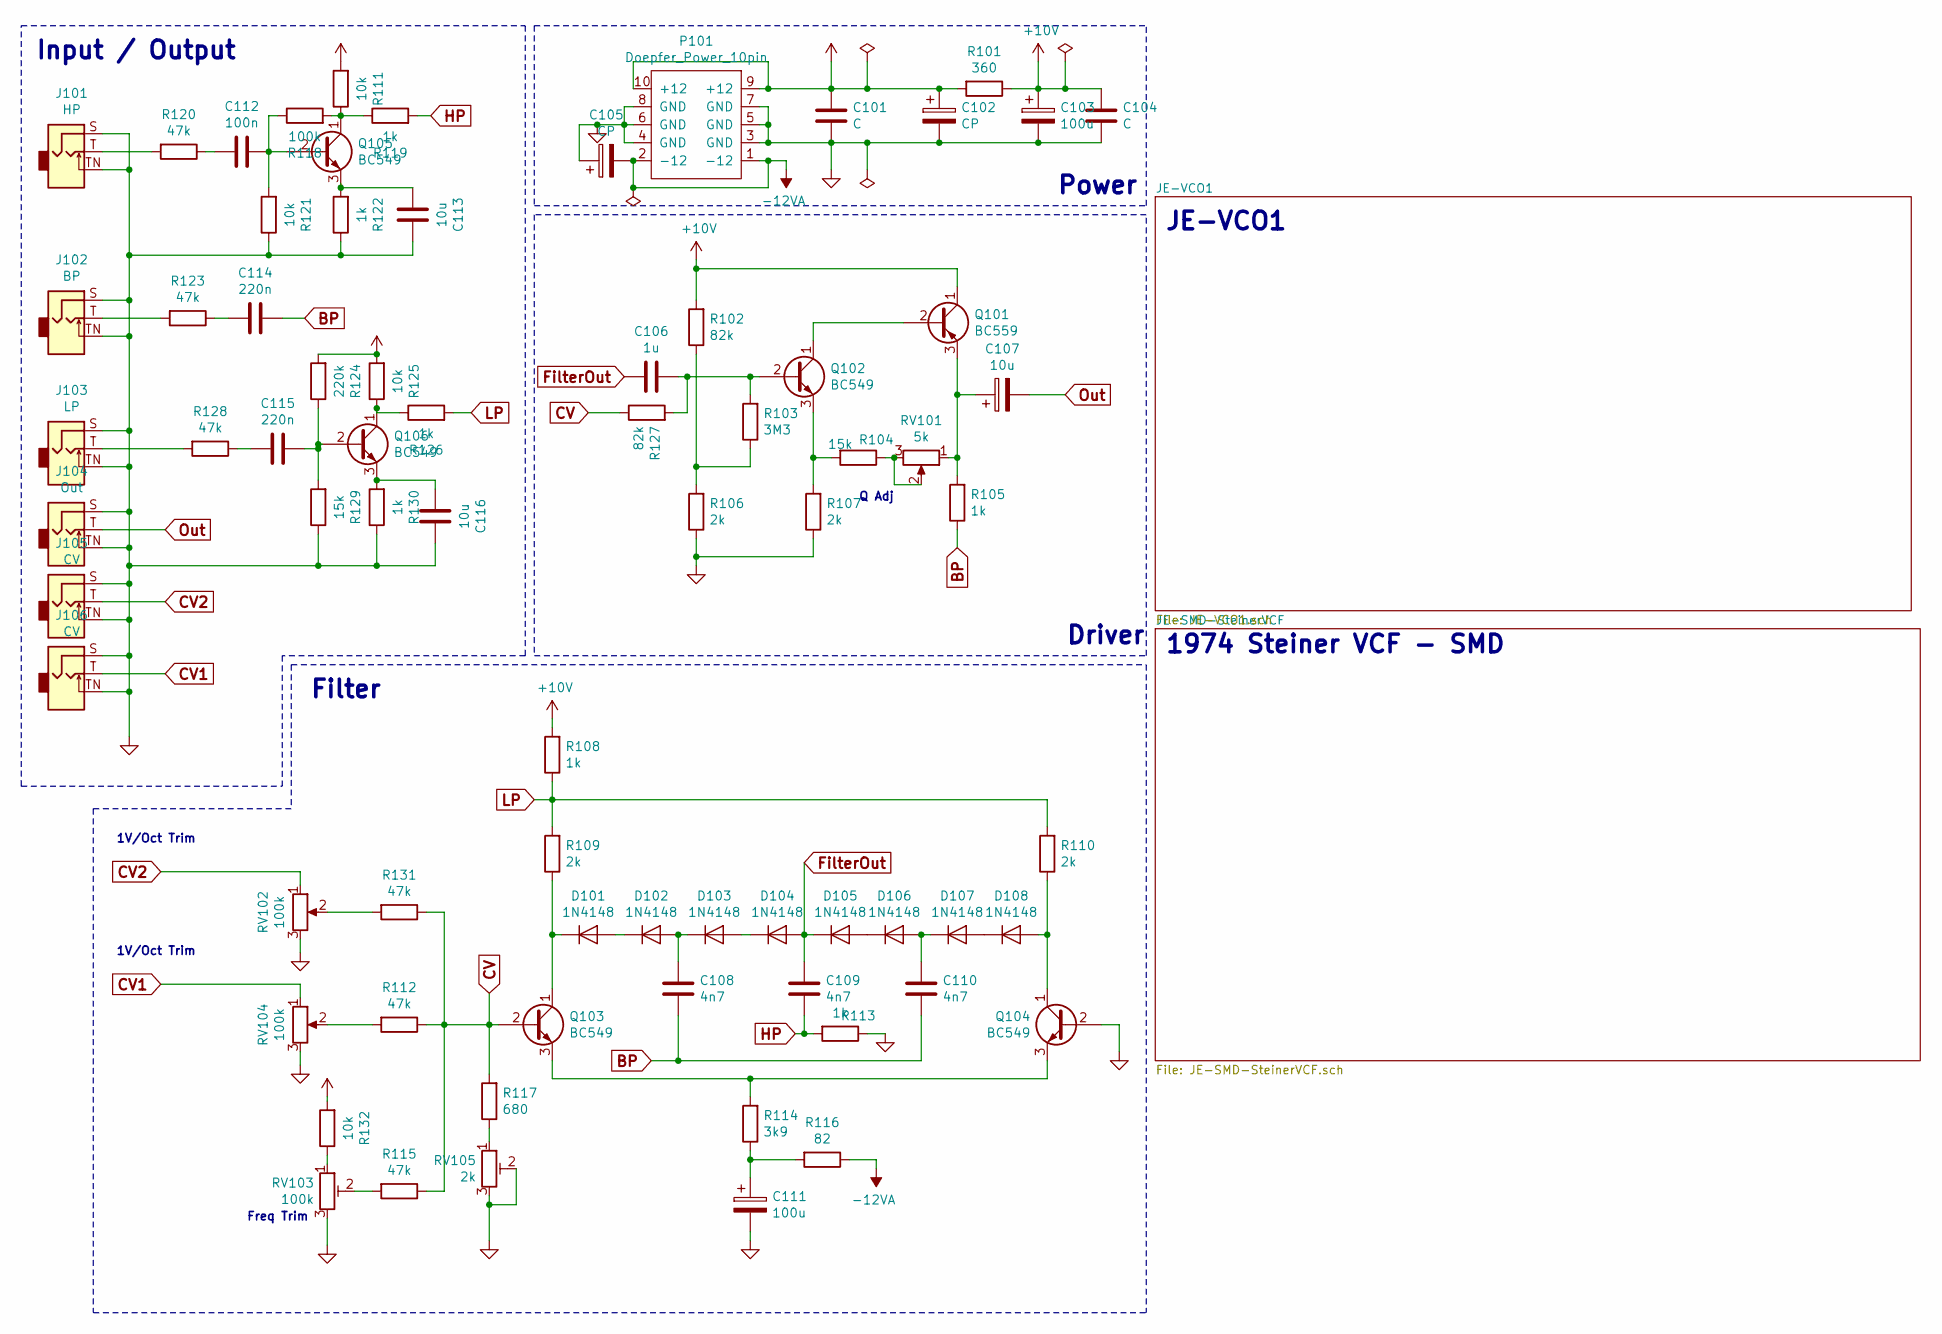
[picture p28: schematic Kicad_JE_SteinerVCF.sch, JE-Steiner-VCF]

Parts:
C101, C104: C; C_Rect_L7.0mm_W2.0mm_P5.00mm
C102, C105: CP; C_Radial_D8.0mm_H7.0mm_P3.50mm
C103, C111: 100u; C_Radial_D8.0mm_H7.0mm_P3.50mm
C106: 1u; C_Rect_L7.0mm_W2.0mm_P5.00mm
C107, C113, C116: 10u; C_Radial_D8.0mm_H7.0mm_P3.50mm
C108, C109, C110: 4n7; C_Rect_L7.0mm_W2.0mm_P5.00mm
C112: 100n; C_Rect_L7.0mm_W2.0mm_P5.00mm
C114, C115: 220n; C_Rect_L7.0mm_W2.0mm_P5.00mm
D101, D102, D103, D104, D105, D106, D107, D108: 1N4148; D_DO-35_SOD27_P7.62mm_Horizontal
J101: HP; PJ301SM
J102: BP; PJ301SM
J103: LP; PJ301SM
J104: Out; PJ301SM
J105, J106: CV; PJ301SM
P101: Doepfer_Power_10pin; IDC-Header_2x05_Pitch2.54mm_Straight
Q101: BC559; TO-92_Inline
Q102, Q103, Q104, Q105, Q106: BC549; TO-92_Inline
R101: 360; R_Axial_DIN0309_L9.0mm_D3.2mm_P12.70mm_Horizontal
R102, R127: 82k; R_Axial_DIN0309_L9.0mm_D3.2mm_P12.70mm_Horizontal
R103: 3M3; R_Axial_DIN0309_L9.0mm_D3.2mm_P12.70mm_Horizontal
R104, R129: 15k; R_Axial_DIN0309_L9.0mm_D3.2mm_P12.70mm_Horizontal
R105, R108, R113, R119, R122, R126, R130: 1k; R_Axial_DIN0309_L9.0mm_D3.2mm_P12.70mm_Horizontal
R106, R107, R109, R110: 2k; R_Axial_DIN0309_L9.0mm_D3.2mm_P12.70mm_Horizontal
R111, R121, R125, R132: 10k; R_Axial_DIN0309_L9.0mm_D3.2mm_P12.70mm_Horizontal
R112, R115, R120, R123, R128, R131: 47k; R_Axial_DIN0309_L9.0mm_D3.2mm_P12.70mm_Horizontal
R114: 3k9; R_Axial_DIN0309_L9.0mm_D3.2mm_P12.70mm_Horizontal
R116: 82; R_Axial_DIN0309_L9.0mm_D3.2mm_P12.70mm_Horizontal
R117: 680; R_Axial_DIN0309_L9.0mm_D3.2mm_P12.70mm_Horizontal
R118: 100k; R_Axial_DIN0309_L9.0mm_D3.2mm_P12.70mm_Horizontal
R124: 220k; R_Axial_DIN0309_L9.0mm_D3.2mm_P12.70mm_Horizontal
RV101: 5k; Potentiometer_China_RK09_Single_Vertical_AJ
RV102, RV103, RV104: 100k; Potentiometer_China_RK09_Single_Vertical_AJ
RV105: 2k; Potentiometer_Piher_PT-6-V_Vertical

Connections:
+10V: C103.1, C104.1, Q101.1 (C), R101.1, R102.2, R108.2
+12VA: C101.1, C102.1, P101.9 (+12), P101.10 (+12), R101.2, R111.2, R124.2, R125.2, R132.2; also elsewhere on the board
-12VA: C105.2, P101.1 (-12), P101.2 (-12), R116.1; also elsewhere on the board
BP: C108.2, C110.2, C114.1, R105.1
CV: Q103.2 (B), R112.1, R115.1, R117.2, R127.1, R131.1
CV1: J106.T, RV104.1
CV2: J105.T, RV102.1
FilterOut: C106.2, C109.1, D104.2 (A), D105.1 (K)
HP: C109.2, R113.2, R119.2
LP: R108.1, R109.2, R110.2, R126.2
unnamed: C106.1, Q102.2 (B), R103.2, R127.2
unnamed: C107.1, Q101.3 (E), R105.2, RV101.1
unnamed: C108.1, D102.2 (A), D103.1 (K)
unnamed: C110.1, D106.2 (A), D107.1 (K)
unnamed: C111.1, R114.1, R116.2
unnamed: C112.1, Q105.2 (B), R118.1, R121.2
unnamed: C112.2, R120.1
unnamed: C113.2, Q105.3 (E), R122.2
unnamed: C114.2, R123.1
unnamed: C115.1, Q106.2 (B), R124.1, R129.2
unnamed: C115.2, R128.1
unnamed: C116.2, Q106.3 (E), R130.2
unnamed: D101.1 (K), Q103.1 (C), R109.1
unnamed: D101.2 (A), D102.1 (K)
unnamed: D103.2 (A), D104.1 (K)
unnamed: D105.2 (A), D106.1 (K)
unnamed: D107.2 (A), D108.1 (K)
unnamed: D108.2 (A), Q104.1 (C), R110.1
unnamed: J101.T, R120.2
unnamed: J102.T, R123.2
unnamed: J103.T, R128.2
unnamed: Q101.2 (B), Q102.1 (C)
unnamed: Q102.3 (E), R104.2, R107.2
unnamed: Q103.3 (E), Q104.3 (E), R114.2
unnamed: Q105.1 (C), R111.1, R118.2, R119.1
unnamed: Q106.1 (C), R125.1, R126.1
unnamed: R102.1, R103.1, R106.2
unnamed: R104.1, RV101.2, RV101.3
unnamed: R112.2, RV104.2
unnamed: R115.2, RV103.2
unnamed: R117.1, RV105.1
unnamed: R131.2, RV102.2
unnamed: R132.1, RV103.1
Out: C107.2, J104.T

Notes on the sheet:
Power
Freq Trim
1V/Oct Trim
Filter
Driver
Q Adj
1974 Steiner VCF - SMD
JE-VCO1
Input / Output

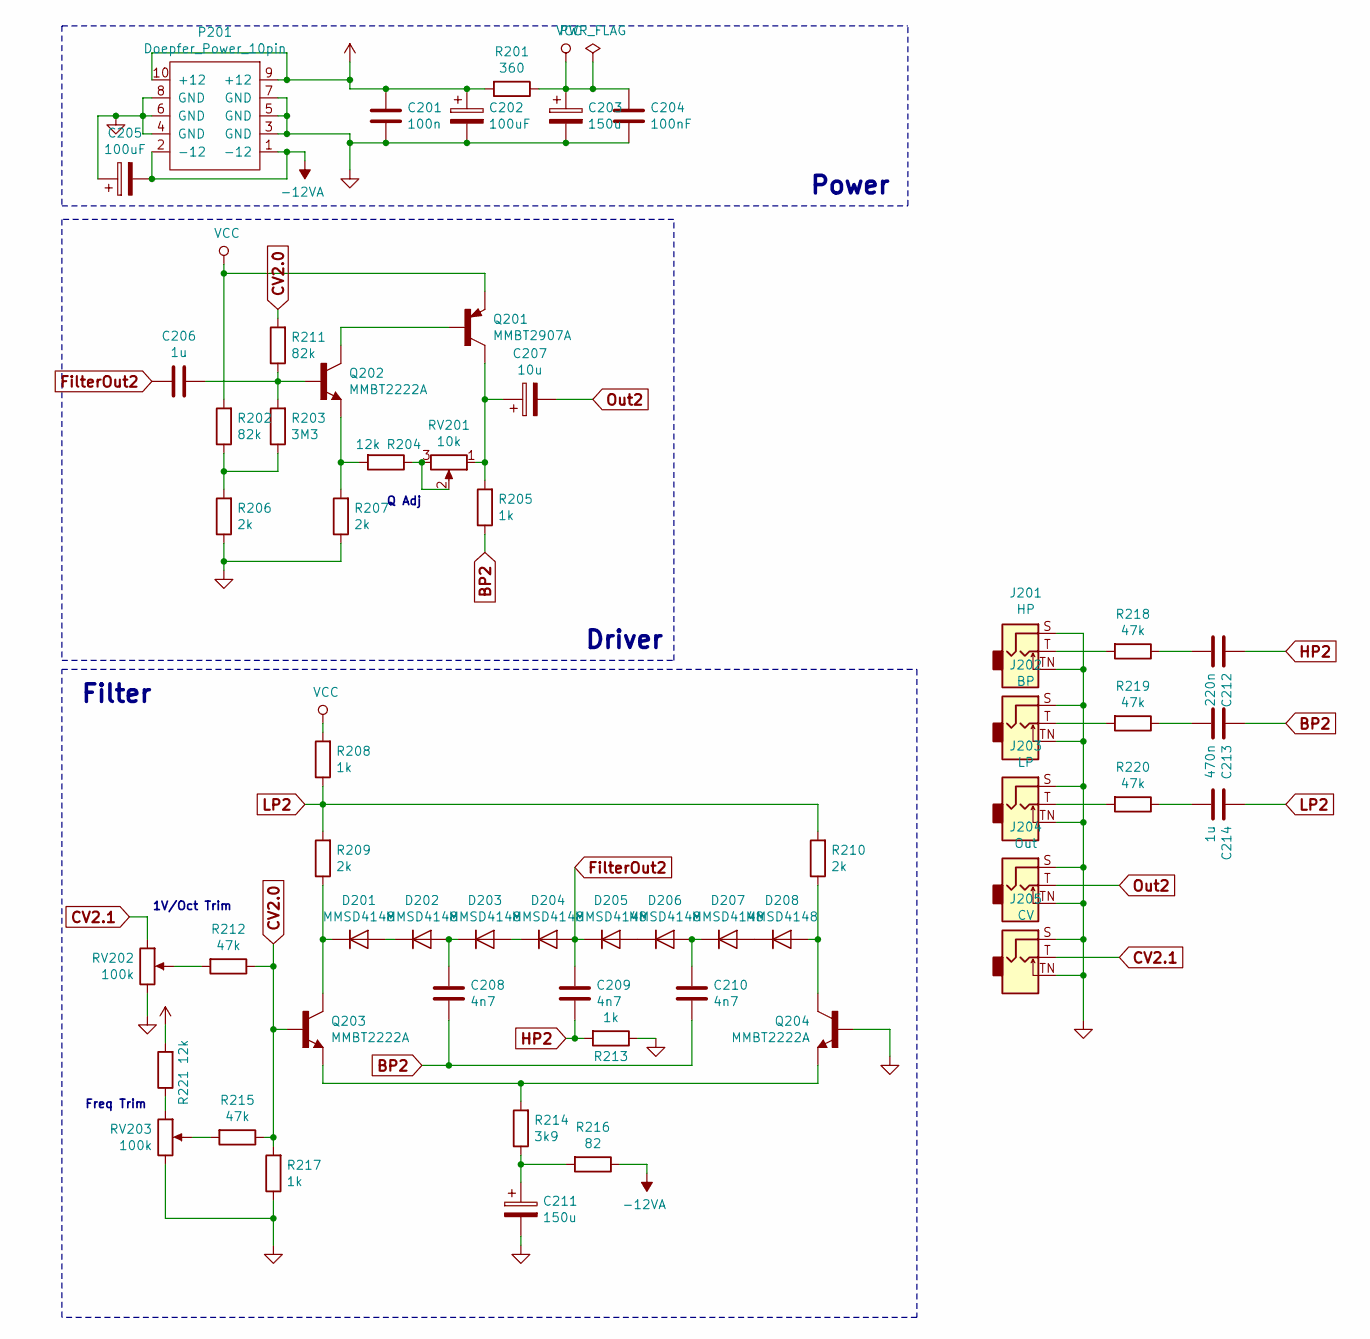
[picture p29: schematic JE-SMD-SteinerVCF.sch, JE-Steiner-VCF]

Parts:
C201: 100n; C_0805_2012Metric_Pad1.15x1.40mm_HandSolder
C202, C205: 100uF; CP_EIA-7343-15_Kemet-W_Pad2.25x2.55mm_HandSolder
C203, C211: 150u; CP_Radial_D10.0mm_P5.00mm
C204: 100nF; C_0805_2012Metric_Pad1.15x1.40mm_HandSolder
C206, C214: 1u; C_0805_2012Metric_Pad1.15x1.40mm_HandSolder
C207: 10u; C_0805_2012Metric_Pad1.15x1.40mm_HandSolder
C208, C209, C210: 4n7; C_0805_2012Metric_Pad1.15x1.40mm_HandSolder
C212: 220n; C_0805_2012Metric_Pad1.15x1.40mm_HandSolder
C213: 470n; C_0805_2012Metric_Pad1.15x1.40mm_HandSolder
D201, D202, D203, D204, D205, D206, D207, D208: MMSD4148; D_SOD-123
J201: HP; PJ301SM
J202: BP; PJ301SM
J203: LP; PJ301SM
J204: Out; PJ301SM
J205: CV; PJ301SM
P201: Doepfer_Power_10pin; IDC-Header_2x05_Pitch2.54mm_Straight
Q201: MMBT2907A; SOT-23-3
Q202, Q203, Q204: MMBT2222A; SOT-23-3
R201: 360; R_0805_2012Metric_Pad1.15x1.40mm_HandSolder
R202, R211: 82k; R_0805_2012Metric_Pad1.15x1.40mm_HandSolder
R203: 3M3; R_0805_2012Metric_Pad1.15x1.40mm_HandSolder
R204, R221: 12k; R_0805_2012Metric_Pad1.15x1.40mm_HandSolder
R205, R208, R213, R217: 1k; R_0805_2012Metric_Pad1.15x1.40mm_HandSolder
R206, R207, R209, R210: 2k; R_0805_2012Metric_Pad1.15x1.40mm_HandSolder
R212, R215, R218, R219, R220: 47k; R_0805_2012Metric_Pad1.15x1.40mm_HandSolder
R214: 3k9; R_0805_2012Metric_Pad1.15x1.40mm_HandSolder
R216: 82; R_0805_2012Metric_Pad1.15x1.40mm_HandSolder
RV201: 10k; Potentiometer_Alps_RK09K_Single_Vertical
RV202, RV203: 100k; AlpsRK09K

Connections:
+12VA: C201.1, C202.1, P201.9 (+12), P201.10 (+12), R201.2, R221.2; also elsewhere on the board
-12VA: C205.2, P201.1 (-12), P201.2 (-12), R216.1; also elsewhere on the board
BP2: C208.2, C210.2, C213.1, R205.1
CV2.0: Q203.1 (B), R211.2, R212.1, R215.1, R217.2
CV2.1: J205.T, RV202.1
FilterOut2: C206.2, C209.1, D204.2 (A), D205.1 (K)
HP2: C209.2, C212.1, R213.2
LP2: C214.1, R208.1, R209.2, R210.2
unnamed: C206.1, Q202.1 (B), R203.2, R211.1
unnamed: C207.1, Q201.3 (C), R205.2, RV201.1
unnamed: C208.1, D202.2 (A), D203.1 (K)
unnamed: C210.1, D206.2 (A), D207.1 (K)
unnamed: C212.2, R218.1
unnamed: C213.2, R219.1
unnamed: C214.2, R220.1
unnamed: D201.1 (K), Q203.3 (C), R209.1
unnamed: D201.2 (A), D202.1 (K)
unnamed: D203.2 (A), D204.1 (K)
unnamed: D205.2 (A), D206.1 (K)
unnamed: D207.2 (A), D208.1 (K)
unnamed: D208.2 (A), Q204.3 (C), R210.1
unnamed: J201.T, R218.2
unnamed: J202.T, R219.2
unnamed: J203.T, R220.2
unnamed: Q201.1 (B), Q202.3 (C)
unnamed: Q202.2 (E), R204.2, R207.2
unnamed: Q203.2 (E), Q204.2 (E), R214.2
unnamed: R202.1, R203.1, R206.2
unnamed: R204.1, RV201.2, RV201.3
unnamed: R212.2, RV202.2
unnamed: R215.2, RV203.2
unnamed: R221.1, RV203.1
Out2: C207.2, J204.T
VCC: C203.1, C204.1, Q201.2 (E), R201.1, R202.2, R208.2

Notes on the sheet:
Power
Freq Trim
1V/Oct Trim
Filter
Driver
Q Adj

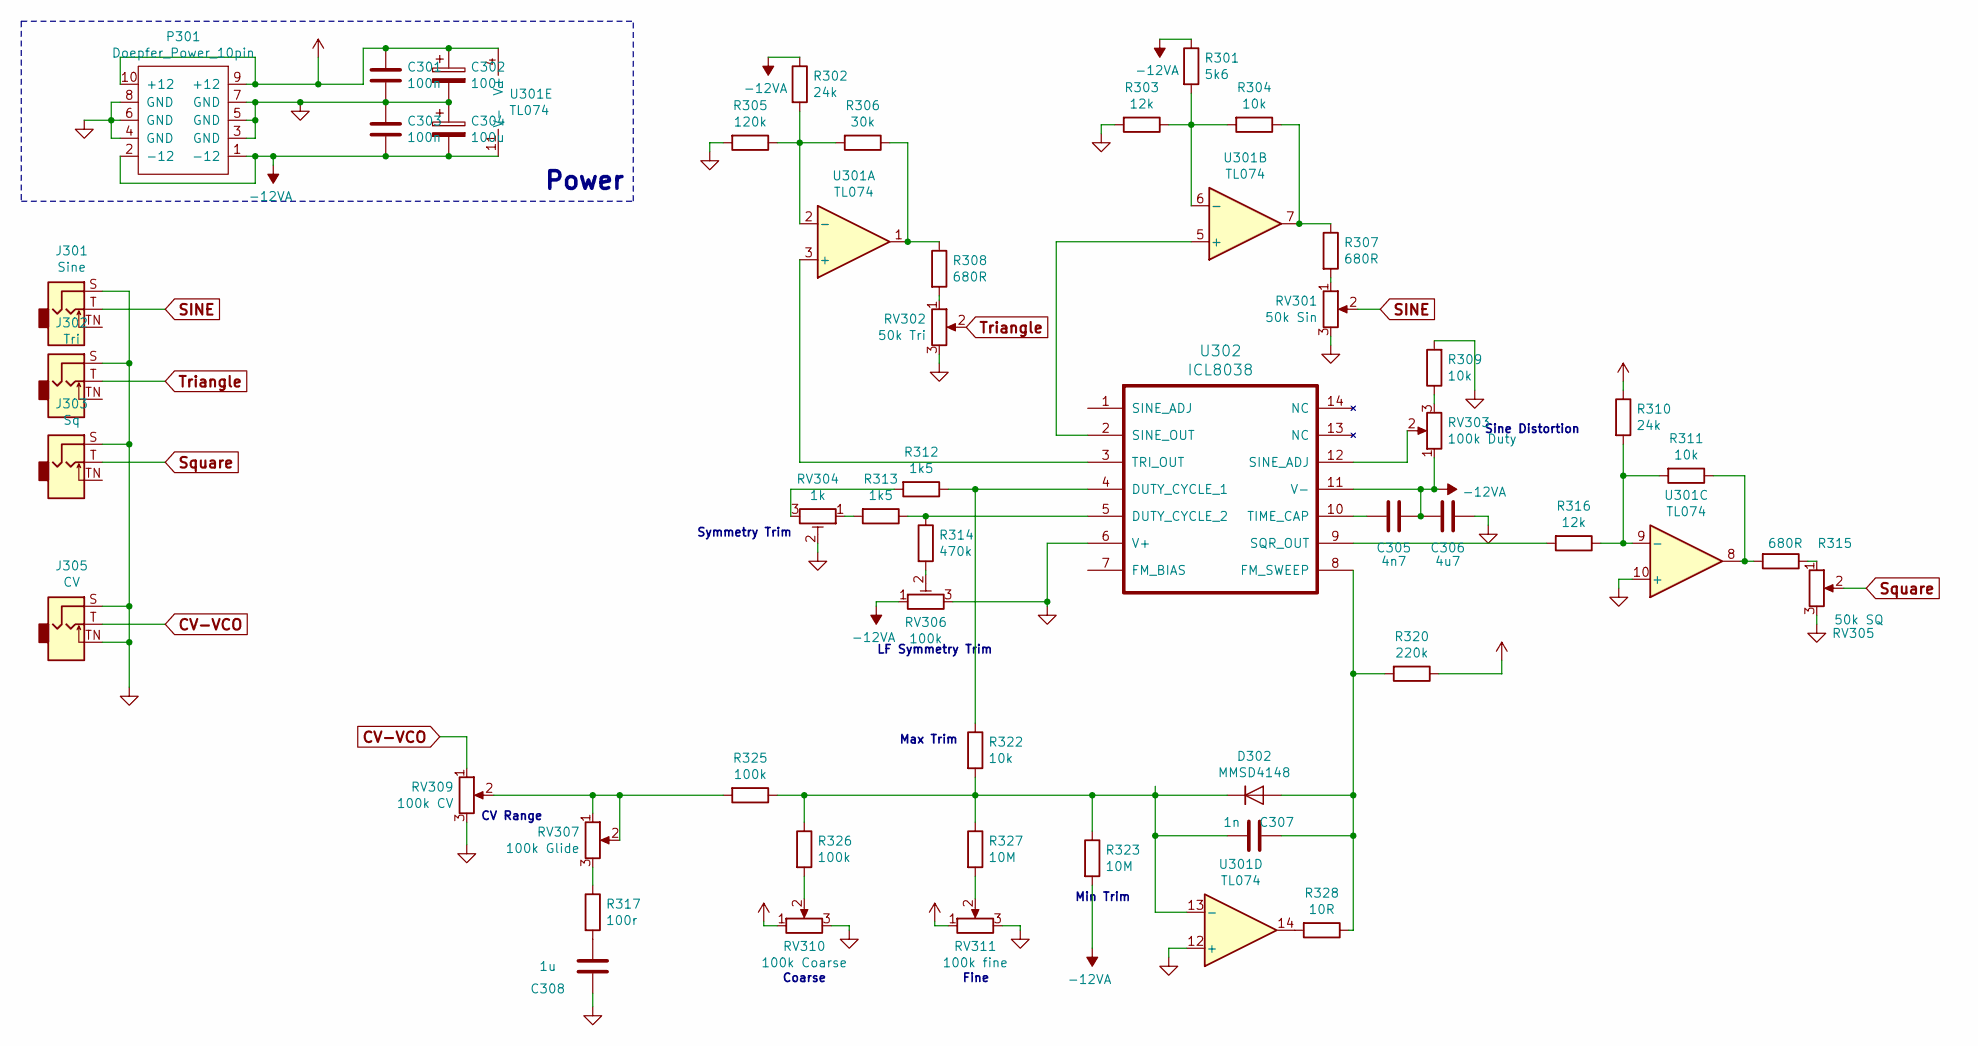
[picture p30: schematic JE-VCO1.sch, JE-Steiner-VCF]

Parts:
C301, C303: 100n; C_0805_2012Metric_Pad1.15x1.40mm_HandSolder
C302, C304: 100u; C_1206_3216Metric
C305: 4n7; C_0805_2012Metric_Pad1.15x1.40mm_HandSolder
C306: 4u7; C_0805_2012Metric_Pad1.15x1.40mm_HandSolder
C307: 1n; C_0805_2012Metric_Pad1.15x1.40mm_HandSolder
C308: 1u; C_0805_2012Metric_Pad1.15x1.40mm_HandSolder
D302: MMSD4148; D_MiniMELF
J301: Sine; PJ301SM
J302: Tri; PJ301SM
J303: Sq; PJ301SM
J305: CV; PJ301SM
P301: Doepfer_Power_10pin; IDC-Header_2x05_Pitch2.54mm_Straight
R301: 5k6; R_0805_2012Metric_Pad1.15x1.40mm_HandSolder
R302, R310: 24k; R_0805_2012Metric_Pad1.15x1.40mm_HandSolder
R303, R316: 12k; R_0805_2012Metric_Pad1.15x1.40mm_HandSolder
R304, R309, R311, R322: 10k; R_0805_2012Metric_Pad1.15x1.40mm_HandSolder
R305: 120k; R_0805_2012Metric_Pad1.15x1.40mm_HandSolder
R306: 30k; R_0805_2012Metric_Pad1.15x1.40mm_HandSolder
R307, R308, R315: 680R; R_0805_2012Metric_Pad1.15x1.40mm_HandSolder
R312, R313: 1k5; R_0805_2012Metric_Pad1.15x1.40mm_HandSolder
R314: 470k; R_0805_2012Metric_Pad1.15x1.40mm_HandSolder
R317: 100r; R_0805_2012Metric_Pad1.15x1.40mm_HandSolder
R320: 220k; R_0805_2012Metric_Pad1.15x1.40mm_HandSolder
R323, R327: 10M; R_0805_2012Metric_Pad1.15x1.40mm_HandSolder
R325, R326: 100k; R_0805_2012Metric_Pad1.15x1.40mm_HandSolder
R328: 10R; R_0805_2012Metric_Pad1.15x1.40mm_HandSolder
RV301: 50k Sin; Potentiometer_China_RK09_Single_Vertical_AJ
RV302: 50k Tri; Potentiometer_China_RK09_Single_Vertical_AJ
RV303: 100k Duty; Potentiometer_China_RK09_Single_Vertical_AJ
RV304: 1k; Potentiometer_Piher_PT-6-V_Vertical
RV305: 50k SQ; Potentiometer_China_RK09_Single_Vertical_AJ
RV306: 100k; Potentiometer_Piher_PT-6-V_Vertical
RV307: 100k Glide; Potentiometer_China_RK09_Single_Vertical_AJ
RV309: 100k CV; Potentiometer_China_RK09_Single_Vertical_AJ
RV310: 100k Coarse; Potentiometer_China_RK09_Single_Vertical_AJ
RV311: 100k fine; Potentiometer_China_RK09_Single_Vertical_AJ
U301: TL074; SOIC-14_3.9x8.7mm_P1.27mm
U302: ICL8038; DIP-14_W7.62mm

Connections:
+12VA: C301.1, C302.1, P301.9 (+12), P301.10 (+12), R310.1, R320.1, RV310.1, RV311.1, U301.4 (V+); also elsewhere on the board
-12VA: C303.2, C304.2, C305.1, C306.2, P301.1 (-12), P301.2 (-12), R301.1, R302.1, R323.2, RV303.1, RV306.1, U301.11 (V-), U302.11 (V-); also elsewhere on the board
CV-VCO: J305.T, RV309.1
unnamed: C305.2, U302.10 (TIME_CAP)
unnamed: C307.1, D302.2 (A), R320.2, R328.1, U302.8 (FM_SWEEP)
unnamed: C307.2, D302.1 (K), R322.2, R323.1, R325.1, R326.1, R327.1, U301.13 (-)
unnamed: C308.2, R317.2
unnamed: R301.2, R303.1, R304.2, U301.6 (-)
unnamed: R302.2, R305.1, R306.2, U301.2 (-)
unnamed: R304.1, R307.1, U301.7
unnamed: R306.1, R308.1, U301.1
unnamed: R307.2, RV301.1
unnamed: R308.2, RV302.1
unnamed: R309.1, RV303.3
unnamed: R310.2, R311.2, R316.1, U301.9 (-)
unnamed: R311.1, R315.2, U301.8
unnamed: R312.1, R322.1, U302.4 (DUTY_CYCLE_1)
unnamed: R312.2, RV304.3
unnamed: R313.1, R314.1, U302.5 (DUTY_CYCLE_2)
unnamed: R313.2, RV304.1
unnamed: R314.2, RV306.2
unnamed: R315.1, RV305.1
unnamed: R316.2, U302.9 (SQR_OUT)
unnamed: R317.1, RV307.3
unnamed: R325.2, RV307.1, RV307.2, RV309.2
unnamed: R326.2, RV310.2
unnamed: R327.2, RV311.2
unnamed: R328.2, U301.14
unnamed: RV303.2, U302.12 (SINE_ADJ)
unnamed: U301.3 (+), U302.3 (TRI_OUT)
unnamed: U301.5 (+), U302.2 (SINE_OUT)
SINE: J301.T, RV301.2
Square: J303.T, RV305.2
Triangle: J302.T, RV302.2

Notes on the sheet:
Power
Sine Distortion
Symmetry Trim
LF Symmetry Trim
CV Range
Coarse
Fine
Max Trim
Min Trim

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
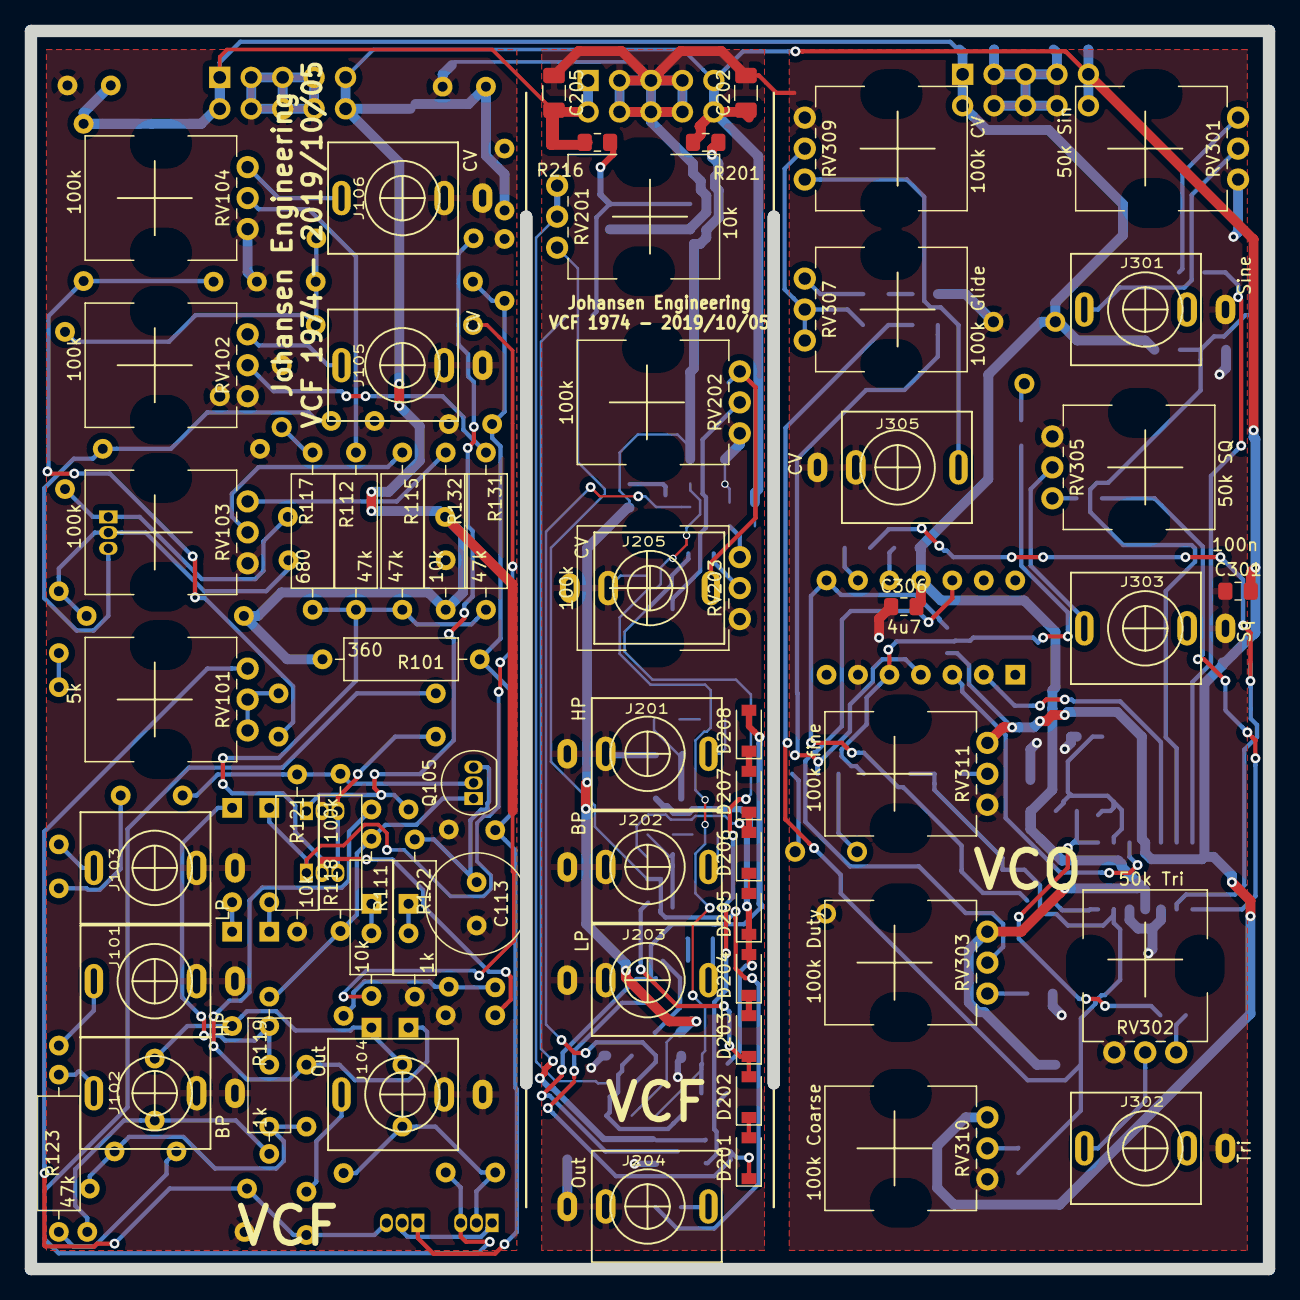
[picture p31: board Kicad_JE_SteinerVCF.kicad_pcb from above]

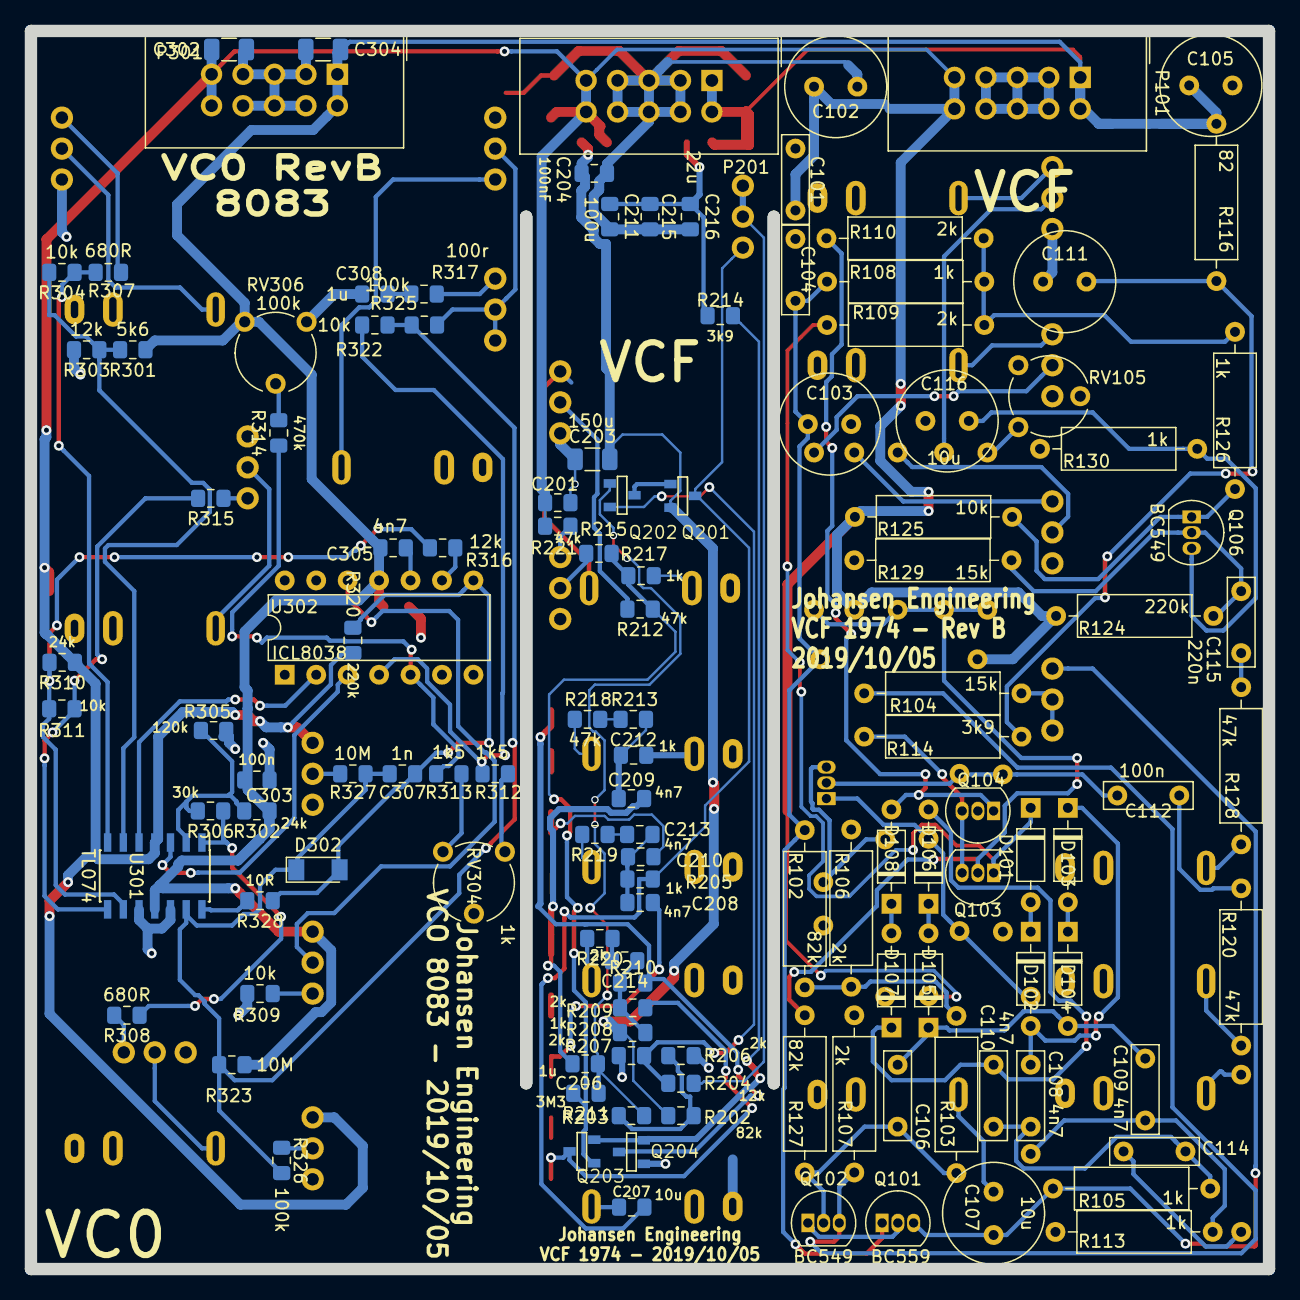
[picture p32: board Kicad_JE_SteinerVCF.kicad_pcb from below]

Board: 2 copper layers, 100.0 x 100.0 mm, 182 parts (124 on the bottom side), 110 nets.

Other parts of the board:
C215, C216: 22u; C_0805_2012Metric_Pad1.15x1.40mm_HandSolder

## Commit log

2019-01-19 Initial schematic - missing driver section
    [Kicad_JE_SteinerVCF.kicad_pcb, Kicad_JE_SteinerVCF.sch]
2019-01-19 Initial complete RevA sch
    [Kicad_JE_SteinerVCF.sch]
2019-01-19 SMD sub sheet
    [JE-SMD-SteinerVCF.sch, Kicad_JE_SteinerVCF.sch]
2019-01-20 ERC, Footprints and Annotation in SCH
    [JE-SMD-SteinerVCF.sch, Kicad_JE_SteinerVCF.sch]
2019-01-20 Net - names conn
    [JE-SMD-SteinerVCF.sch]
2019-01-20 Place SMD init
    [JE-SMD-SteinerVCF.sch, Kicad_JE_SteinerVCF.kicad_pcb, _saved_JE-SMD-SteinerVCF.sch]
2019-01-20 SMD section routed RevA
    [JE-SMD-SteinerVCF.sch, Kicad_JE_SteinerVCF.kicad_pcb, Kicad_JE_SteinerVCF.sch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]
2019-01-20 THT Start - Label upd
    [Kicad_JE_SteinerVCF.kicad_pcb, _saved_Kicad_JE_SteinerVCF.sch]
2019-01-20 THT update - minor
    [_saved_Kicad_JE_SteinerVCF.sch]
2019-01-20 THT complete placement - RevA
    [Kicad_JE_SteinerVCF.kicad_pcb]
2019-01-20 Connection Cleanup on both VCF
    [Kicad_JE_SteinerVCF.kicad_pcb]
2019-01-20 Label Placement SMD and THT - RevA
    [Kicad_JE_SteinerVCF.kicad_pcb]
2019-01-20 ICL8083 VCO added sch, ERC and footprints
    [JE-SMD-SteinerVCF.sch, JE-VCO1.sch, Kicad_JE_SteinerVCF.sch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]
2019-01-20 VCO ICL8083 netlist and PCB import
    [Kicad_JE_SteinerVCF.kicad_pcb]
2019-01-20 Components for faceplate mounted
    [Kicad_JE_SteinerVCF.kicad_pcb, _saved_JE-VCO1.sch]
2019-01-21 VCO inspiration
    [JE-VCO1.sch, _saved_JE-VCO1.sch]
2019-01-26 PCB - Components placed on VCO
    [Kicad_JE_SteinerVCF.kicad_pcb]
2019-01-26 All routed - And 3D
    [Kicad_JE_SteinerVCF.kicad_pcb]
2019-01-26 Gerber and DRC
    [Kicad_JE_SteinerVCF-B.Cu.gbr, Kicad_JE_SteinerVCF-B.Mask.gbr, Kicad_JE_SteinerVCF-B.Paste.gbr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]
2019-01-26 New Gerber
    [Kicad_JE_SteinerVCF-B.Cu.gbr, Kicad_JE_SteinerVCF-B.Mask.gbr, Kicad_JE_SteinerVCF-B.Paste.gbr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]
2019-01-26 BOM generated
2019-02-19 RevB init
    [JE-SMD-SteinerVCF.sch, JE-VCO1.sch, Kicad_JE_SteinerVCF.kicad_pcb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]
2019-02-19 VCF Rev B THT + Extra inspiration
    [JE-SMD-SteinerVCF.sch, JE-VCO1.sch, Kicad_JE_SteinerVCF.sch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]
2019-02-19 fix reintroduced
    [Kicad_JE_SteinerVCF.sch]
2019-02-19 mod fix
    [Kicad_JE_SteinerVCF.sch]
2019-02-19 RevB SMD
    [_saved_JE-SMD-SteinerVCF.sch]
2019-02-19 VCF SMD
    [JE-SMD-SteinerVCF.sch, _saved_JE-SMD-SteinerVCF.sch]
2019-02-19 VCO minor
    [JE-VCO1.sch]
2019-02-20 VCO 0R indicate
    [JE-VCO1.sch]
2019-02-20 vco updated values
    [JE-VCO1.sch]
2019-02-20 prototype pictures
2019-03-16 RevB Sch initiated
    [JE-VCO1.sch]
2019-03-16 RevB second step
    [JE-VCO1.sch]
2019-03-16 DRC RevB
    [JE-SMD-SteinerVCF.sch, JE-VCO1.sch, Kicad_JE_SteinerVCF.sch]
2019-03-16 Label sheets
    [JE-SMD-SteinerVCF.sch, JE-VCO1.sch, Kicad_JE_SteinerVCF.sch]
2019-03-16 VCO_ICL8083 Schematic.png
2019-10-05 Rev B init
    [JE-SMD-SteinerVCF.kicad_pcb]
2019-10-05 8083 routed
    [_saved_Kicad_JE_SteinerVCF.sch]
2019-10-05 VCF SMD routed
    [JE-VCO1.sch, Kicad_JE_SteinerVCF.kicad_pcb, Kicad_JE_SteinerVCF.sch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]
2019-10-05 fiddleing w THT VCF
    [Kicad_JE_SteinerVCF.kicad_pcb, _saved_Kicad_JE_SteinerVCF.sch]
2019-10-05 VCF THT Placed
    [Kicad_JE_SteinerVCF.kicad_pcb]
2019-10-05 Routed THT
    [Kicad_JE_SteinerVCF.kicad_pcb]
